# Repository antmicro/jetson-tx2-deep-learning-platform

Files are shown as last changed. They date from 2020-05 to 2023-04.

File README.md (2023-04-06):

# Antmicro TX2 Deep Learning Platform

Copyright (c) 2016-2023 [Antmicro](https://www.antmicro.com)



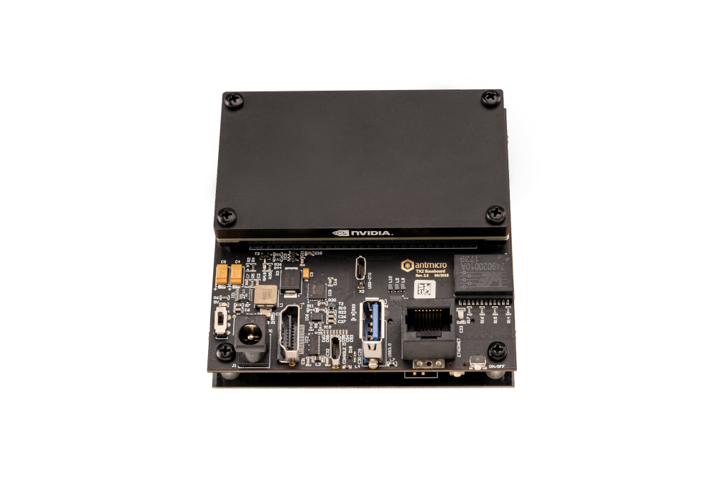
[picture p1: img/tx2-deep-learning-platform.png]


## Overview

This project contains open hardware design files for Antmicro's TX2 Deep Learning Platform built around NVIDIA [Jetson TX2 Module](https://developer.nvidia.com/embedded/jetson-tx2).
The TX2 Deep Learning Platform is a small, modular multi-camera kit for the NVIDIA Jetson TX2 module.
It consists of a baseboard and a camera adapter for interchangeable video input modules.
The baseboard is electrically compatible with the NVIDIA Jetson TX2/TXi and legacy TX1 module.
The baseboard offers typical IO interfaces along with miniPCIe/SATA expansion slots.
Thanks to its straightforward design, the camera adapter can be easily adjusted to custom image sensor setups composed of up to 6 independent cameras connected to the TX2 module over the MIPI CSI-2 interface.

## Project structure:

* `Baseboard` - contains PCB design files for the Jetson TX1/TX2/TX2i baseboard along with basic documentation
* `CameraAdapter` - contains PCB design files for the camera adapter, which break-routes the MIPI CSI-2 interfaces from the baseboard on three FFC connectors
* `img` - contains graphics for this README
* `3DModels` - contains files defining the mechanical model of the assembled platform

The PCB projects include basic documentation including schematics, assembly drawings (in the PDF format) along with the bill of material (BOM).
The PCB project files were prepared in Altium Designer 14.1

## Key Features

* USB 3.0 host interface
* HDMI output
* Micro USB OTG connector
* Serial debug console over micro USB
* Configurable mPCIe/mSATA card holder
* Gigabit Ethernet RJ45 connector
* 3x 50-pin FFC camera connectors exposing up to 6 MIPI CSI-2 camera interfaces
* Autostart circuitry
* RTC battery backup
* EEPROM for storing board ID/SN
* CAN interface (optional, not populated by default)
* 12-19V DC supply voltage
* 90 x 90 mm dimensions

## Getting started

The platform can be produced and assembled using the provided design files.
Please, refer to the mechanical layers for more information regarding the PCB stackup recommended for fabrication.
The platform accepts power supply voltage in the 12-19VDC range.
It is recommended to use a 12V 2A DC supply to power the platform.
The baseboard has a slide switch which activates the autostart function.
If the switch is on, the TX2 module will boot automatically. Otherwise, it will start after pressing the power button.
There is a [basic BSP](https://github.com/antmicro/tx2-deep-learning-kit-bsp) released by Antmicro for this hardware platform along with compilation and usage instructions.
The BSP configuration will most likely need to be adjusted for the video accessories used with the TX2 Deep Learning Platform.
Nevertheless, the remaining on-board IO interfaces should be working properly.

## Supported accessories

The TX2 Deep Learning Platform is compatible with a range of video accessories designed by Antmicro.

The board exposes MIPI CSI-2 interfaces using unified 50-pin connectors that are electrically compatible with a variety of video accessories created by Antmicro:

* [SDI-MIPI Video converter](https://github.com/antmicro/sdi-mipi-video-converter)
* [FRAMOS camera adapter](https://github.com/antmicro/framos-csi-adapter)
* [Allied Vision Alvium Camera Adapter](https://github.com/antmicro/alvium-flexible-csi-adapter)
* [HDMI-MIPI bridge](https://github.com/antmicro/hdmi-mipi-bridge)
* [OV9281 Dual camera board](https://github.com/antmicro/ov9281-camera-board)

## License

This project is licensed under the [Apache-2.0](LICENSE) license.

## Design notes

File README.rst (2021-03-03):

===================================
Antmicro TX2 Deep Learning Platform
===================================

Copyright (c) 2016-2021 `Antmicro <https://www.antmicro.com>`_

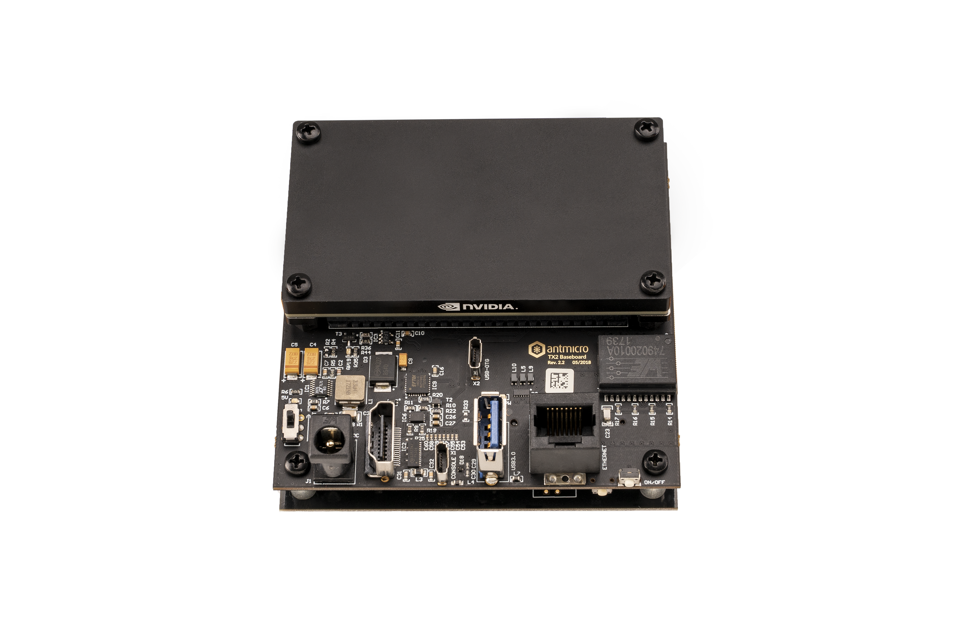
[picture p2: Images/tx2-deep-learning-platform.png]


Overview
========

This repository contains open hardware design files for Antmicro's TX2 Deep Learning Platform built around NVIDIA `Jetson TX2 Module <https://developer.nvidia.com/embedded/jetson-tx2>`_.
The TX2 Deep Learning Platform is a small, modular multi-camera kit for the NVIDIA Jetson TX2 module.
It consists of a baseboard and a camera adapter for interchangeable video input modules.
The baseboard is electrically compatible with the NVIDIA Jetson TX2/TXi and legacy TX1 module.
The baseboard offers typical IO interfaces along with miniPCIe/SATA expansion slots.
Thanks to its straightforward design, the camera adapter can be easily adjusted to custom image sensor setups composed of up to 6 independent cameras connected to the TX2 module over the MIPI CSI-2 interface.

Repository structure:
---------------------

* ``Baseboard`` - contains PCB design files for the Jetson TX1/TX2/TX2i baseboard along with basic documentation
* ``CameraAdapter`` - contains PCB design files for the camera adapter, which break-routes the MIPI CSI-2 interfaces from the baseboard on three FFC connectors
* ``Images`` - contains graphics for this README
* ``3DModels`` - contains files defining the mechanical model of the assembled platform

The PCB projects include basic documentation including schematics, assembly drawings (in the PDF format) along with the bill of material (BOM).
The PCB project files were prepared in Altium Designer 14.1

Key Features
============

* USB 3.0 host interface
* HDMI output
* Micro USB OTG connector
* Serial debug console over micro USB
* Configurable mPCIe/mSATA card holder
* Gigabit Ethernet RJ45 connector
* 3x 50-pin FFC camera connectors exposing up to 6 MIPI CSI-2 camera interfaces
* Autostart circuitry
* RTC battery backup
* EEPROM for storing board ID/SN
* CAN interface (optional, not populated by default)
* 12-19V DC supply voltage
* 90 x 90 mm dimensions

Board layout & dimensions
=========================

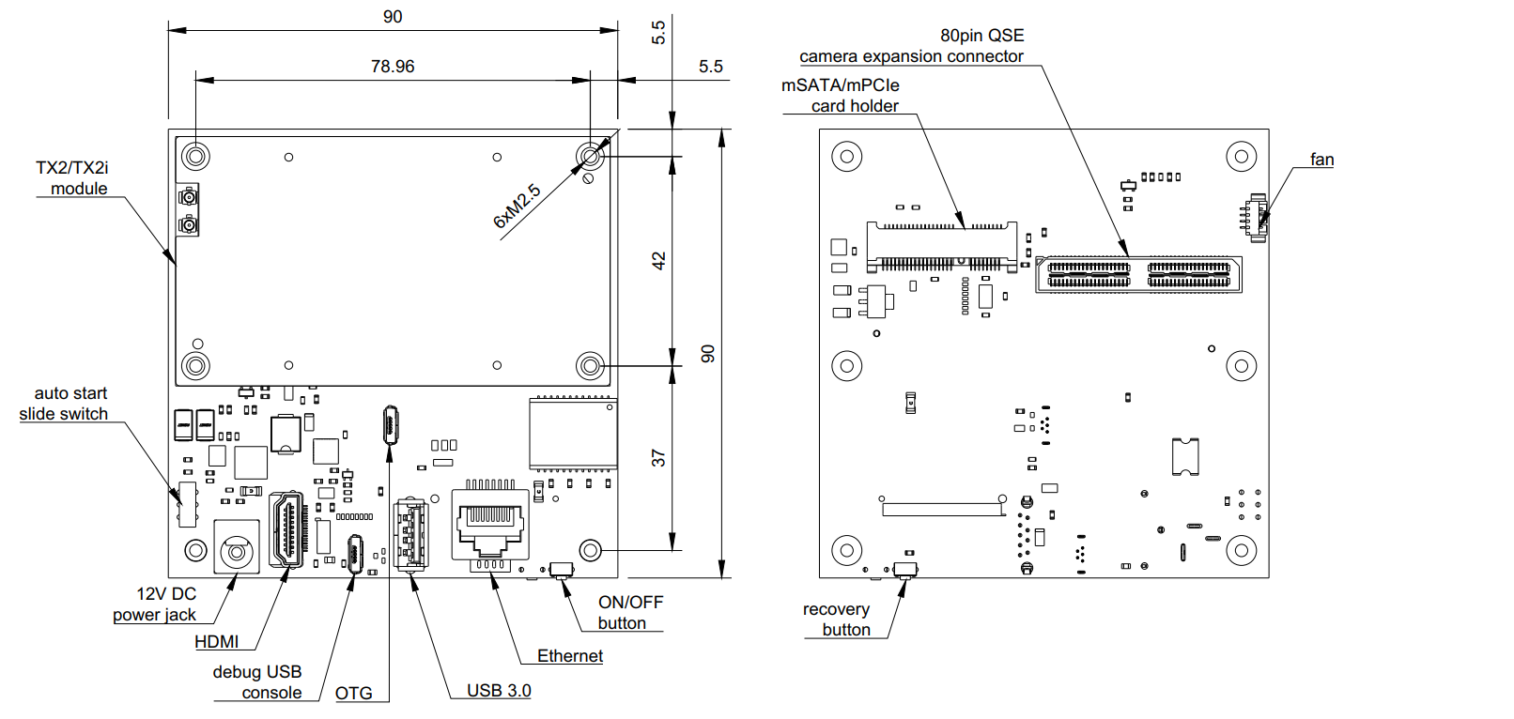
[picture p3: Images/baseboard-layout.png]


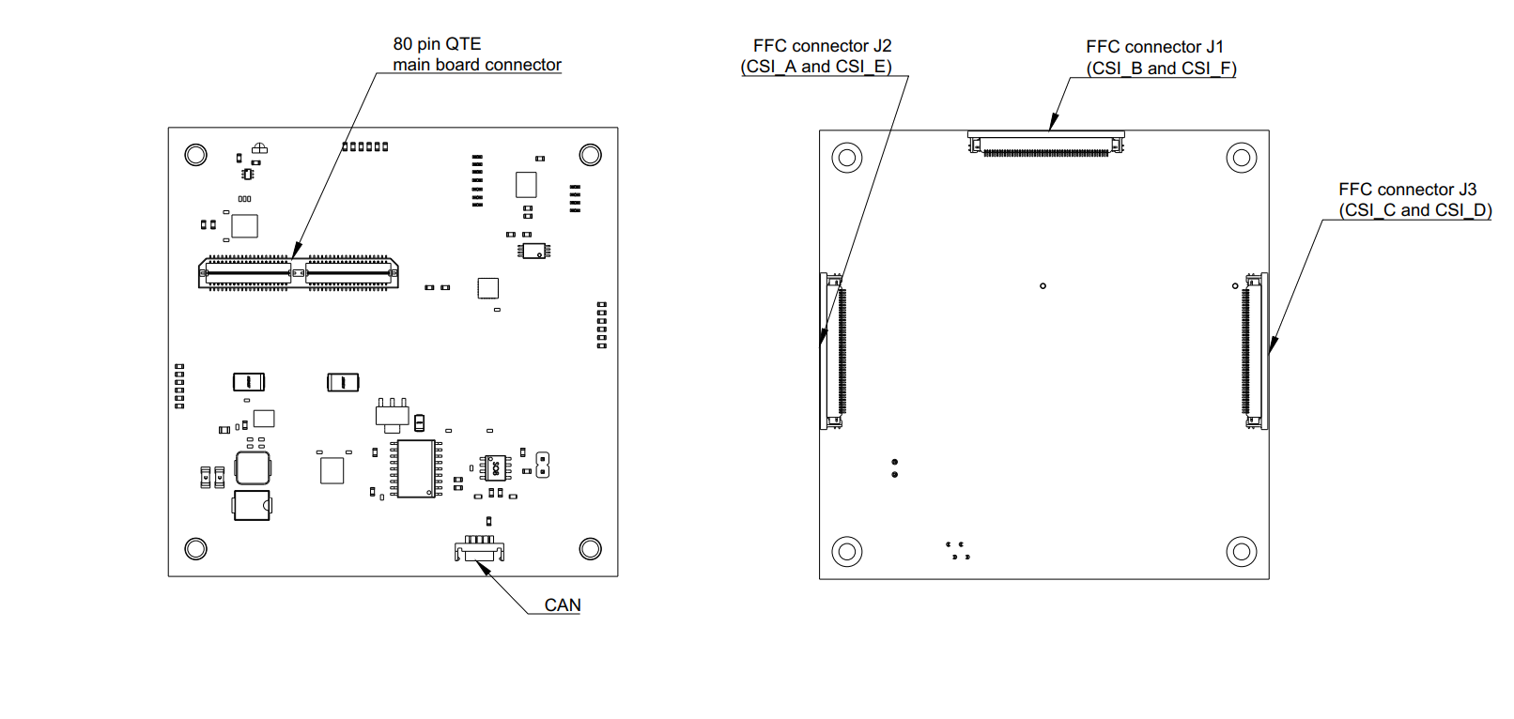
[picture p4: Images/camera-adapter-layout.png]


Getting started
===============

The platform can be produced and assembled using the provided design files.
Please, refer to the mechanical layers for more information regarding the PCB stackup recommended for fabrication.
The platform accepts power supply voltage in the 12-19VDC range.
It is recommended to use a 12V 2A DC supply to power the platform.
The baseboard has a slide switch which activates the autostart function.
If the switch is on, the TX2 module will boot automatically. Otherwise, it will start after pressing the power button.
There is a `basic BSP <https://github.com/antmicro/tx2-deep-learning-kit-bsp>`_ released by Antmicro for this hardware platform along with compilation and usage instructions.
The BSP configuration will most likely need to be adjusted for the video accessories used with the TX2 Deep Learning Platform.
Nevertheless, the remaining on-board IO interfaces should be working properly.

Supported accessories
=====================

The TX2 Deep Learning Platform is compatible with a range of video accessories designed by Antmicro.
Some of them, like the `OV9281 Camera Board <https://github.com/antmicro/ov9281-camera-board>`_ are available as Open Hardware designs.

License
=======

`Apache-2.0 <LICENSE>`_

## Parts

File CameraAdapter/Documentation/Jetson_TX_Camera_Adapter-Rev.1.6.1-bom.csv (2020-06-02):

Designator | Value | Description | Manufacturer | Part Symbol | Quantity
C1 | 22u | Tantalum SMT Capacitor 22uF Case KEMET_C | KEMET | T491C226K025AT | 1
C2 | 470n/16V | MLCC SMT Capacitor 470nF 0402 16V | TDK | C1005X5R1C474K050BC | 1
C3, C4 | 47u | MLCC SMT Capacitor 47uF 1206 | MURATA | GRM31CC80J476KE18L | 2
C5 | 10p | MLCC SMT Capacitor 10pF 0402 | MULTICOMP | MC0402N100D500CT | 1
C6 | 10n | MLCC SMT Capacitor 10nF 0402 | AVX | 04025G103ZAT2A | 1
C7 | 470p | MLCC SMT Capacitor 470pF 0402 | MULTICOMP | MC0402B471J500CT | 1
C15 | 10u | Tantalum SMT Capacitor 10uF Case KEMET_C | KEMET | T491C106K025AT | 1
C16 | 10u | Tantalum SMT Capacitor 10uF Case KEMET_A | VISHAY | 293D106X9016A2TE3 | 1
C18, C19, C20 | 100n | MLCC SMT Capacitor 100nF 0402 | MULTICOMP | MC0402X104M100CT | 3
C28, C61 | 100n | MLCC SMT Capacitor 100nF 0603 | WALSIN | 0603B104K500CT | 2
D1 | MBRS540T3G | ON SEMICONDUCTOR MBRS540T3G Rectifier Diode, Single, 40 V, 5 A, 500 mV, 190 A | ON SEMICONDUCTOR | MBRS540T3G | 1
IC1 | TCA9548ARGER | TCA9548ARGER I2C SWITCH W/ RESET, 8-CH, VQFN-24 | TEXAS INSTRUMENTS | TCA9548ARGER | 1
IC4 | LT3976EMSE#PBF | LINEAR TECHNOLOGY LT3976EMSE#PBF DC-DC CONVERTER, 2MHZ, 5A, MSOP-16 | LINEAR TECHNOLOGY | LT3976EMSE#PBF | 1
IC6 | NCV1117ST50T3G | ON SEMICONDUCTOR NCV1117ST50T3G Fixed LDO Voltage Regulator, 20V in, 1.07V Dropout, 5V/1A out, SOT-223-3 | ON SEMICONDUCTOR | NCV1117ST50T3G | 1
IC7 | NTS0104PW | 4 bit voltage level translator | NXP | NTS0104PW | 1
IC14 | TCA9554A | Remote 8bit I2C SMBus I/O expander | Texas Instruments | TCA9554A | 1
IC15 | RM24C128DS-LTAI-B | EEPROM with UID and OTP registers. | Adesto | RM24C128DS-LTAI-B | 1
J1, J2, J3 | 68715014522 | 0.50mm SMT ZIF Horizontal Bottom Contact WR-FPC | WURTH ELEKTRONIK | 68715014522 | 3
J6 | QTE-040-03-L-D-A | SAMTEC QTE-040-03-L-D-A Stacking Board Connector, Dual Row, QTE Series, 80 Contacts, Header, 0.8 mm, Surface Mount | SAMTEC | QTE-040-03-L-D-A | 1
L1 | 74437346033 | 3.3 uH, 5.0A, 0.03 ohm, SMD Power Inductor | WURTH ELEKTRONIK | 74437346033 | 1
LED1 | LED-LiteON-LTST-S326KGJRKT | Standard LEDs - SMD Green/Red Clear 571nm/631nm | Lite-On | LTST-S326KGJRKT | 1
Q1 | Si1922EDH | 20 V, dual N-channel Trench MOSFET | Vishay | Si1922EDH | 1
R2, R7 | 470R | SMT Resistor 470R 0603 | BOURNS | CR0603-JW-471GLF | 2
R3 | 1M | SMT Resistor 1M 0603 0.1% | TE | CPF0603B1M0E | 1
R4 | 130k | SMT Resistor 2R 0402 | MULTICOMP | MCMR04X1303FTL | 1
R5 | 2R | SMT Resistor 2R 0402 | MULTICOMP | MC00625W040212R0 | 1
R6 | 576k | SMT Resistor 576k 0805 0.1% | PANASONIC ELECTRONIC COMPONENTS | ERA-6AEB5763V | 1
R16, R17, R18, R19, R24, R25, R27, R31, R32, R39, R40, R54, R76, R77 | 2k | SMT Resistor 2k 0603 | MULTICOMP | MCMR06X2001FTL | 14
R42, R43, R47 | 2k2 | SMT Resistor 2k2 0603 | MULTICOMP | MCMR06X2201FTL | 3
R49, R51, R53, R56, R58, R60, R62, R64, R66, R69, R70 | 0R | SMT Resistor 0402 | MULTICOMP | MCMR04X000 PTL | 11
R72, R73, R74, R75 | 0R | SMT Resistor 0R 0603 | BOURNS | CR0603-J/-000ELF | 4
SP1, SP2, SP3, SP4 | 9774030960R | ROUND SPACER STEEL 3MM unthreaded | WURTH ELEKTRONIK | 9774030960 | 4

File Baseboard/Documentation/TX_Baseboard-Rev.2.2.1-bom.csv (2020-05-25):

Designator | Value | Description | Manufacturer | Quantity | Layer | Part Symbol
5V, GP19, PCI/SATA | KPT-1608SGC | LED Green 0603 case | KINGBRIGHT | 3 | Top, Top, Bottom | KPT-1608SGC
AUTO START | JS202011CQN | Sub-Miniature Slide Switch | C&K | 1 | Top | JS202011CQN
C1, C44, C45 | 10p | MLCC SMT Capacitor 10pF 0603 | JOHANSON TECHNOLOGY | 3 | Top, Bottom, Bottom | 251R14S100GV4T
C2 | 470n | MLCC SMT Capacitor 470nF 0603 | TDK | 1 | Top | C1608X5R1H474K080AB
C3 | 47u | MLCC SMT Capacitor 47uF 1206 | MURATA | 1 | Top | GRM31CC80J476KE18L
C4, C5 | 22u | Tantalum SMT Capacitor 22uF Case KEMET_C | KEMET | 2 | Top | T491C226K025AT
C6, C11, C32, C46, C47, C48 | 10n | MLCC SMT Capacitor 10nF 0603 | AVX | 6 | Top, Top, Top, Bottom, Bottom, Bottom | 06031C103JAT2A
C7 | 470p | MLCC SMT Capacitor 470pF 0603 | AVX | 1 | Top | 06031C471JAT2A
C8, C17, C35 | 10u | Tantalum SMT Capacitor 10uF Case KEMET_A | VISHAY | 3 | Bottom, Bottom, Top | 293D106X9016A2TE3
C9 | 4u7 | Tantalum SMT Capacitor 4u7F Case KEMET_A | KEMET | 1 | Top | T491A475K010AT
C10, C16, C26, C27, C28, C31, C40, C41, C43, C61 | 100n | MLCC SMT Capacitor 100nF 0603 | WALSIN | 10 | Top, Top, Top, Top, Top, Top, Top, Top, Top, Bottom | 0603B104K500CT
C12 | 4u7 | MLCC SMT Capacitor 4u7F 0603 | MULTICOMP | 1 | Top | MC0603X475K6R3CT
C13, C14, C36, C37, C38, C39, C52 | 10u | MLCC SMT Capacitor 10uF 0603 | MULTICOMP | 7 | Bottom, Bottom, Bottom, Top, Bottom, Bottom, Top | MC0603X106M6R3CT
C15 | 10n | MLCC SMT Capacitor 10nF 1206 | MULTICOMP | 1 | Bottom | MC1206B103K631CT
C18 | 10u | Tantalum SMT Capacitor 10uF Case KEMET_C | KEMET | 1 | Top | T491C106K025AT
C19, C20, C21, C22, C24, C25, C49, C50, C53, C54, C55, C56, C57, C58, C59, C60 | 100n | MLCC SMT Capacitor 100nF 0402 | MULTICOMP | 16 | Bottom, Bottom, Bottom, Bottom, Bottom, Bottom, Bottom, Bottom, Top, Top, Top, Top, Top, Top, Top, Top | MC0402X104M100CT
C23 | 1n | MLCC SMT Capacitor 1nF 1206 | AVX | 1 | Top | 12061A102JAT2A
C29, C30 | 47p | MLCC SMT Capacitor 47pF 0402 | KEMET | 2 | Top | C0402C470J5GACTU
C33 | 100u | Tantalum SMT Capacitor 100uF Case KEMET_A | VISHAY | 1 | Bottom | 298D107X06R3A2T
C34, C42 | 1u | MLCC SMT Capacitor 1uF 0603 | MULTICOMP | 2 | Bottom, Top | MC0603X105M6R3CT
C51 | 80mF | CAP 80MF 3.3V SURFACE MOUNT | SEIKO | 1 | Top | XH414HG-IV01E
D1, D2, D18 | TPD2E009DRTR | ESD Suppressors 2-CH | Texas Instruments | 3 | Bottom, Bottom, Top | TPD2E009DRTR
D3 | MBRS540T3G | ON SEMICONDUCTOR MBRS540T3G Rectifier Diode, Single, 40 V, 5 A, 500 mV, 190 A | ON SEMICONDUCTOR | 1 | Top | MBRS540T3G
D4 | SMBJ20CA-TR | DIODE, TVS, 20V, 600W | STMICROELECTRONICS | 1 | Bottom | SMBJ20CA-TR
D7 | 1N4148WS | Diode small signal | MULTICOMP | 1 | Top | 1N4148WS
D8 | TPD6E05U06 | ESD Suppressors 6-CH Pass through layout | Texas Instruments | 1 | Top | TPD6E05U06RVZR
F1 | 3.0A | 3.0A, 6V, PTC Resettabe Fuse | BOURNS | 1 | Bottom | MF-LSMF300X-2
HDMI | Molex-04765-1000 | HDMI connector vertical | Molex | 1 | Top | 47659-1000
IC1 | LT3976EMSE#PBF | LINEAR TECHNOLOGY LT3976EMSE#PBF DC-DC CONVERTER, 2MHZ, 5A, MSOP-16 | LINEAR TECHNOLOGY | 1 | Top | LT3976EMSE#PBF
IC2 | TPD8S009 | 8-Channel ESD Protection for DisplayPort and HDMI | TEXAS INSTRUMENTS | 1 | Top | TPD8S009DSMR
IC3 | LP2992AIM5-1.8 | LDO 1.8V 250mA | TEXAS INSTRUMENTS | 1 | Top | LP2992AIM5-1.8/NOPB
IC4 | LM3671MF-1.5 | DC/DC Buck Converter | TEXAS INSTRUMENTS | 1 | Bottom | LM3671MF-1.5/NOPB
IC5, IC7 | AP1117E33G-13 | IC, LDO, REG, 3.3V, SOT223 | DIODES INC. | 2 | Bottom, Top | AP1117E33G-13
IC6 | PCA9517ATP | I2C BUS REPEATER W/ LEVEL TRANS, HWSON-8 | NXP | 1 | Top | PCA9517ATP
IC8 | SEAM-50-02.0-S-08-2-A-K-TR | TX1 module (board connector) | Samtec | 1 | Top | SEAM-50-02.0-S-08-2-A-K-TR
IC9 | FT232RQ | USB to serial UART interface | FTDI | 1 | Top | FT232RQ-REEL
IC10 | NCP380HSNAJAAT1G | POWER LOAD SWITCH, HIGH SIDE | ON Semiconductor | 1 | Bottom | NCP380HSNAJAAT1G
IC11 | LM3881 | TEXAS INSTRUMENTS LM3881MME/NOPB Power Sequencer, 3-Monitors, 2.7V-5.5Vin,VSSOP-8 | TEXAS INSTRUMENTS | 1 | Top | LM3881MME
IC12 | SN74LVC1G86DCKR | 2 input XOR gate | Texas Instruments | 1 | Top | SN74LVC1G86DCKR
IC13 | CBTL02042ABQ | IC MUX/DEMUX 2:1 PCI 20DHVQFN | NXP Semiconductors | 1 | Bottom | CBTL02042ABQ,115
IC14 | TCA9554ADBQR | Remote 8bit I2C SMBus I/O expander | Texas Instruments | 1 | Top | TCA9554ADBQR
IC15 | RM24C128DS-LTAI-B | EEPROM with UID and OTP registers. | Adesto | 1 | Top | RM24C128DS-LTAI-B
J1 | WE_694106402002 | WURTH ELEKTRONIK 694106402002 POWER ENTRY, JACK, 2MM, VERTICAL THT, 3A | WURTH ELEKTRONIK | 1 | Top | 694106402002
J2 | QSE-040-01-L-D-A | SAMTEC QSE-040-01-L-D-A Stacking Board Connector, Dual Row, QSE Series, Receptacle, 0.8 mm, 80 Contacts, Surface Mount | SAMTEC | 1 | Bottom | QSE-040-01-L-D-A
J3 | WE_634108149621 | Modular Connectors / Ethernet Connectors WR-MJ Mod Jk 8P8C Solder Tab w/Mylar | WURTH ELEKTRONIK | 1 | Top | 634108149621
J4 | WE_692121430000 | WURTH ELEKTRONIK 692121430000 USB Connector, USB Type A, USB 3.0, Receptacle, 9 Ways, PCB Mount, Vertical | WURTH ELEKTRONIK | 1 | Top | 692121430000
J5 | Molex_67910-5700 | PCIe Mini Card Holder 4mm | Molex | 1 | Bottom | 67910-5700
J6 | 653104131822 | HEADER 4POS MALE HORIZ 1.25MM SMD | WURTH ELEKTRONIK | 1 | Bottom | 653104131822
L1 | IHLP2525CZER3R3M01 | 3.3 uH, +/- 20%, Shielded, 0.02 ohm, 8 A | VISHAY | 1 | Top | IHLP2525CZER3R3M01
L3 | 742792022 | WURTH ELEKTRONIK - 742792022 - FERRITE BEAD, 0.05OHM, 2A, 0805 | WURTH ELEKTRONIK | 1 | Top | 742792022
L4 | BLM18SG121TN1D | FERRITE BEAD, 0.025OHM, 3A, 0603 | MURATA | 1 | Top | BLM18SG121TN1D
L5, L9, L10, L11, L13 | DLW21SN900SQ2 | Common mode choke | MURATA | 5 | Top, Top, Top, Bottom, Bottom | DLW21SN900SQ2L
L6 | BLM18EG221SN1D | MURATA BLM18EG221SN1D FERRITE BEAD, 0.05OHM, 2A, 0603 | MURATA | 1 | Bottom | BLM18EG221SN1D
L7, L12 | BLM18PG330SN1D | MURATA BLM18PG330SN1D FERRITE BEAD, 0.025OHM, 3A, 0603 | MURATA | 2 | Top, Bottom | BLM18PG330SN1D
L8 | LQH3NPN2R2NM0L | INDUCTOR, 2.2 uH, +/- 30%, 1212, 90 MHz, 0.073 ohm | MURATA | 1 | Bottom | LQH3NPN2R2NM0L
LED2 | KPT-1608EC | LED Red 0603 case | KINGBRIGHT | 1 | Top | KPT-1608EC
M1, M2, M3, M4 | 9774110360 | M3x11.6 | WURTH ELEKTRONIK | 4 | Bottom | 9774110360
M6, M7 | 9774030360 | M3x3 | WURTH ELEKTRONIK | 2 | Bottom | 9774030360
M8, M9, M10, M11 |  |  | Dremec | 4 | None | 316/3.2x07
On/Off, REC | TL3340AF160QG | E-SWITCH TL3340AF160QG SWITCH, TACTILE SPST 50mA, SMD GULL WING | E-SWITCH | 2 | Top, Bottom | TL3340AF160QG
PCIE | MECH-Molex-48099-5701 | PCI Express/PCI Connectors LATCH ASSY FOR MINIP CI-ENEW TYPE W/COVER | Molex | 1 | None | 48099-5701
R1 | 1M | SMT Resistor 1M 0603 | BOURNS | 1 | Top | CR0603-JW-105GLF
R3, R20, R22 | 4k7 | SMT Resistor 4k7 0603 | BOURNS | 3 | Bottom, Top, Top | CR0603-FX-4701ELF
R4, R24, R28, R37, R44, R72 | 0R | SMT Resistor 0R 0603 | BOURNS | 6 | Top, Bottom, Bottom, Bottom, Top, Top | CR0603-J/-000ELF
R5 | 2R | SMT Resistor 2R 0603 | MULTICOMP | 1 | Top | MCSR06W2R00FTL
R6, R18 | 470R | SMT Resistor 470R 0603 | BOURNS | 2 | Top, Bottom | CR0603-JW-471GLF
R7 | 54k9 | SMT Resistor 54k9 0603 | PANASONIC ELECTRONIC COMPONENTS | 1 | Top | ERJ3EKF5492V
R8 | 316k | SMT Resistor 316k 0603 | MULTICOMP | 1 | Top | MC0063W06031316K
R9, R10, R11, R19, R21, R32, R34, R36, R38, R39, R45, R46 | 10k | SMT Resistor 10k 0603 | BOURNS | 12 | Top, Top, Top, Top, Bottom, Top, Bottom, Top, Top, Bottom, Top, Top | CR0603-JW-103ELF
R13 | 47k | SMT Resistor 47k 0603 | MULTICOMP | 1 | Top | MCWR06X4702FTL
R14, R15, R16, R17 | 75R | SMT Resistor 75R 0603 | MULTICOMP | 4 | Top | MCWR06X75R0FTL
R26, R42, R43 | 2k2 | SMT Resistor 2k2 0603 | MULTICOMP | 3 | Bottom, Bottom, Top | MCMR06X2201FTL
R27 | 13k | SMT Resistor 13k 0603 | PANASONIC ELECTRONIC COMPONENTS | 1 | Bottom | ERJ3GEYJ133V
R29, R40, R41 | 22R | SMT Resistor 22R 0603 | BOURNS | 3 | Top, Bottom, Bottom | CR0603-JW-220GLF
R30, R47, R48 | 100R | SMT Resistor 100R 0603 | MULTICOMP | 3 | Bottom, Top, Top | MC0063W06035100R
R31, R35 | 330R | SMT Resistor 330R 0603 | BOURNS | 2 | Bottom, Top | CR0603-FX-3300GLF
R51, R52, R53, R55, R56, R64, R65, R69, R70 | 2k2 | RES, 2k2, 0402, 5% | MULTICOMP | 9 | Top | MCWR04X2201FTL
R60, R66 | 0R | SMT Resistor 0402 | MULTICOMP | 2 | Top | MCMR04X000 PTL
T1 | 749020010A | LAN TRANSFORMER, 10/100/1000 BASE-T | WURTH ELEKTRONIK | 1 | Top | 749020010A
T2 | BSS138PW | MOSFET, N CH, 60V, 0.2A | NXP | 1 | Top | BSS138PW
T3, T4, T5 | PMV16XN | MOSFET Transistor, N Channel, 6.8 A, 20 V, 0.016 ohm, 4.5 V | NXP | 3 | Top, Top, Bottom | PMV16XN
T6, T7 | BSS138AKA | MOSFET, N CH, 60V, 0.2A | NXP | 2 | Top | BSS138AKA
X1, X2 | USB3106-30-0230-A | Micro USB A/B TH Vertical | GLOBAL CONNECTOR TECHNOLOGY | 2 | Top | USB3105-30-A

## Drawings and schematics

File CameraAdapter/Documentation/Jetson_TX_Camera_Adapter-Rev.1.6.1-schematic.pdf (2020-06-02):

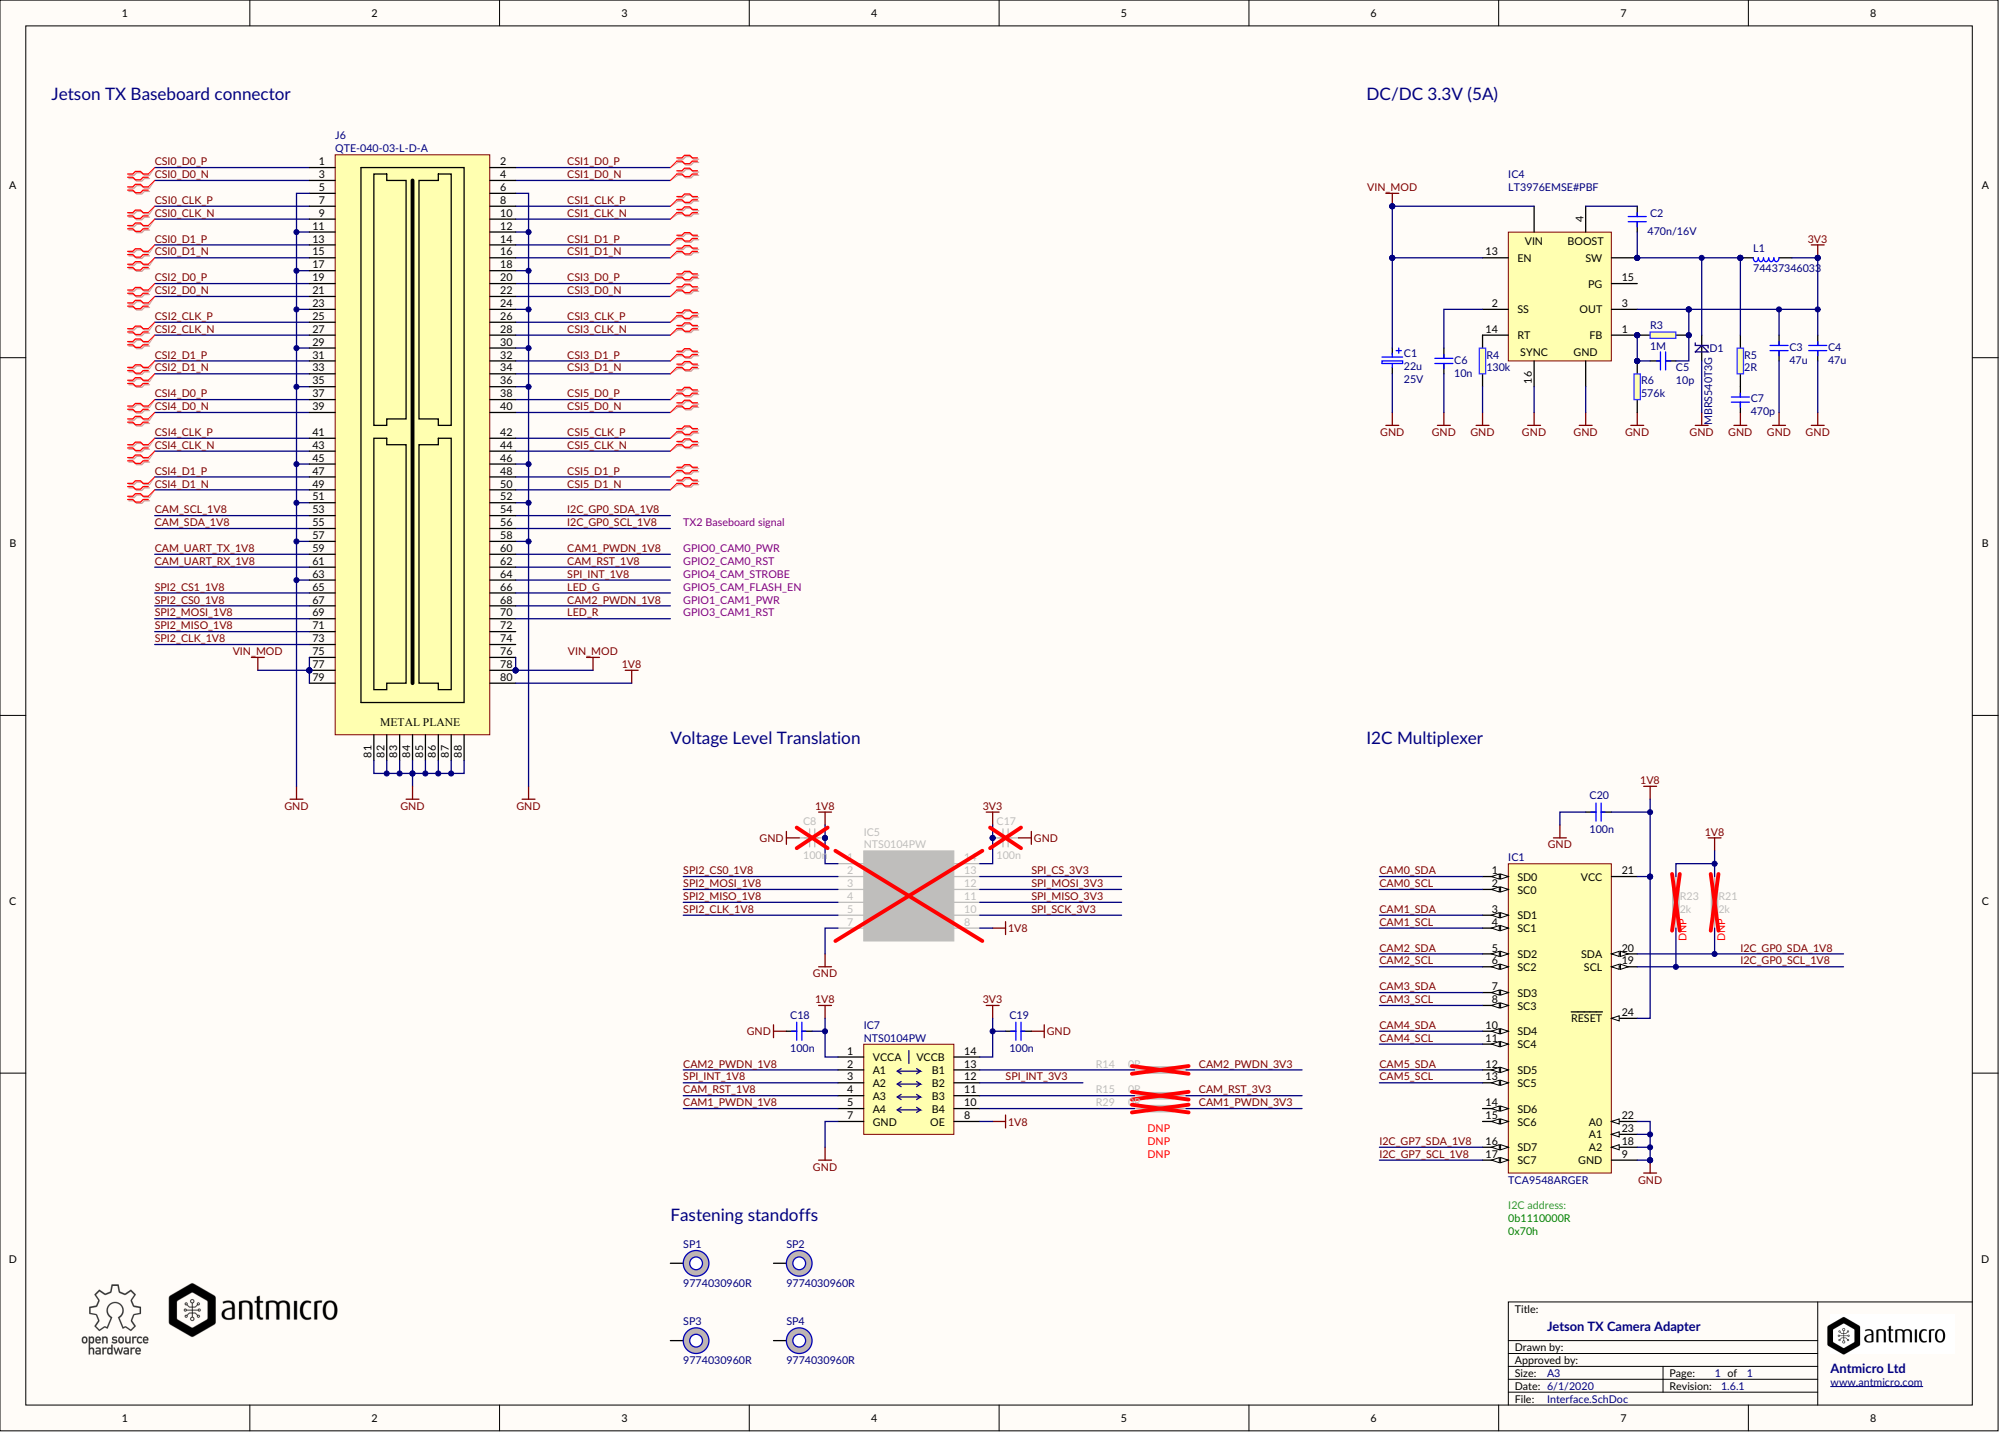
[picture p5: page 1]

Jetson TX Baseboard connector

Title:
Jetson TX Camera Adapter

Size: A3 | Page: 1 of 1
Date: 6/1/2020 | Revision: 1.6.1

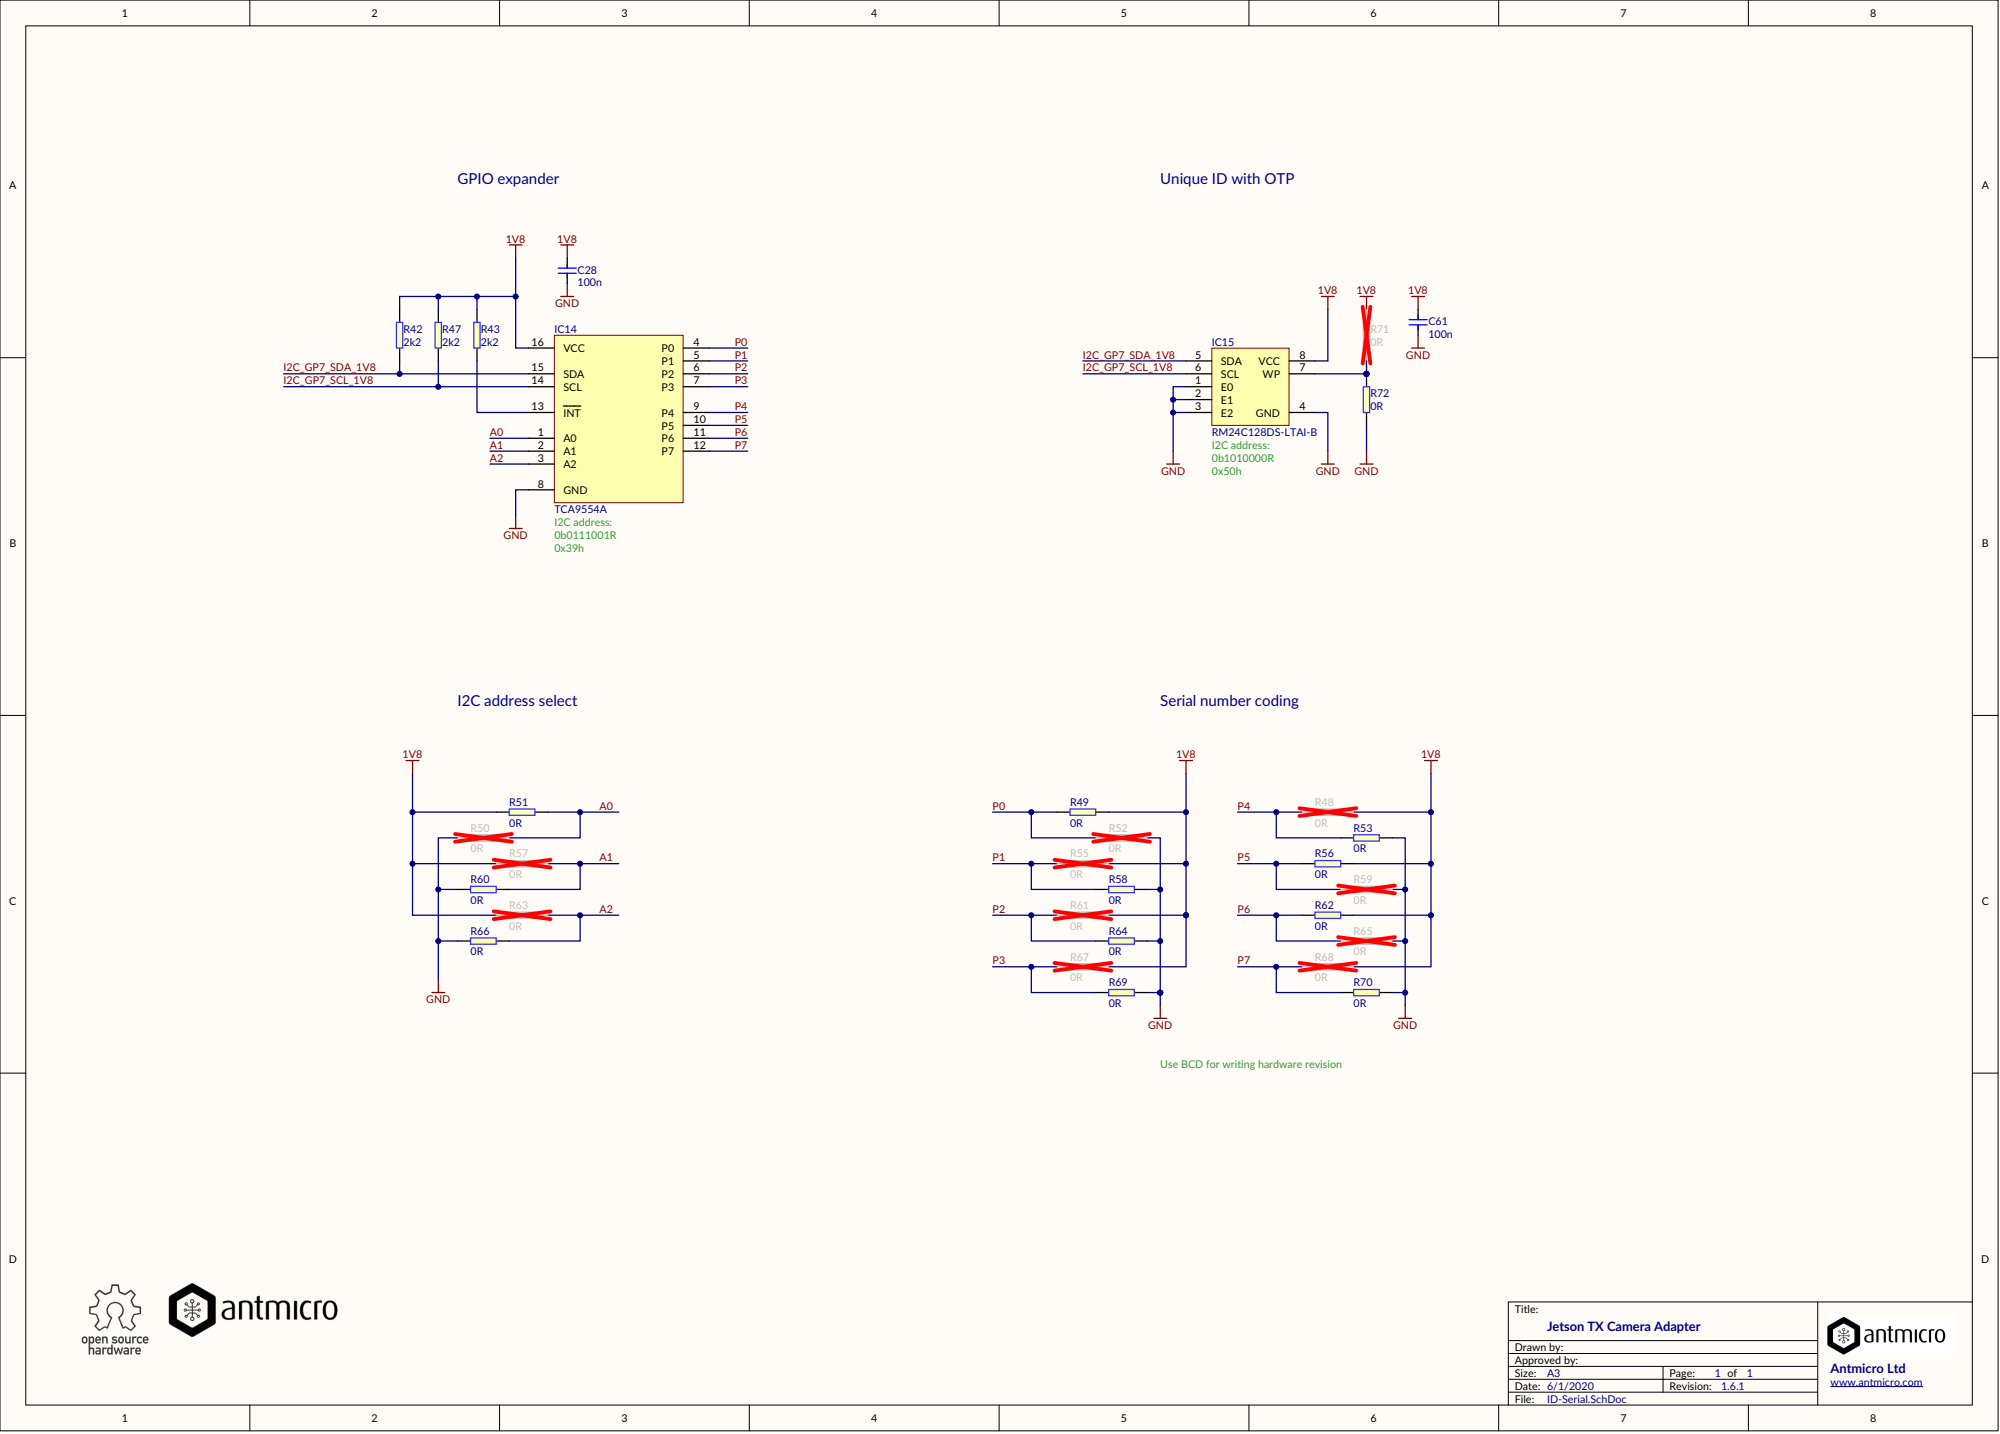
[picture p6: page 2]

Unique ID with OTP

Use BCD for writing hardware revision

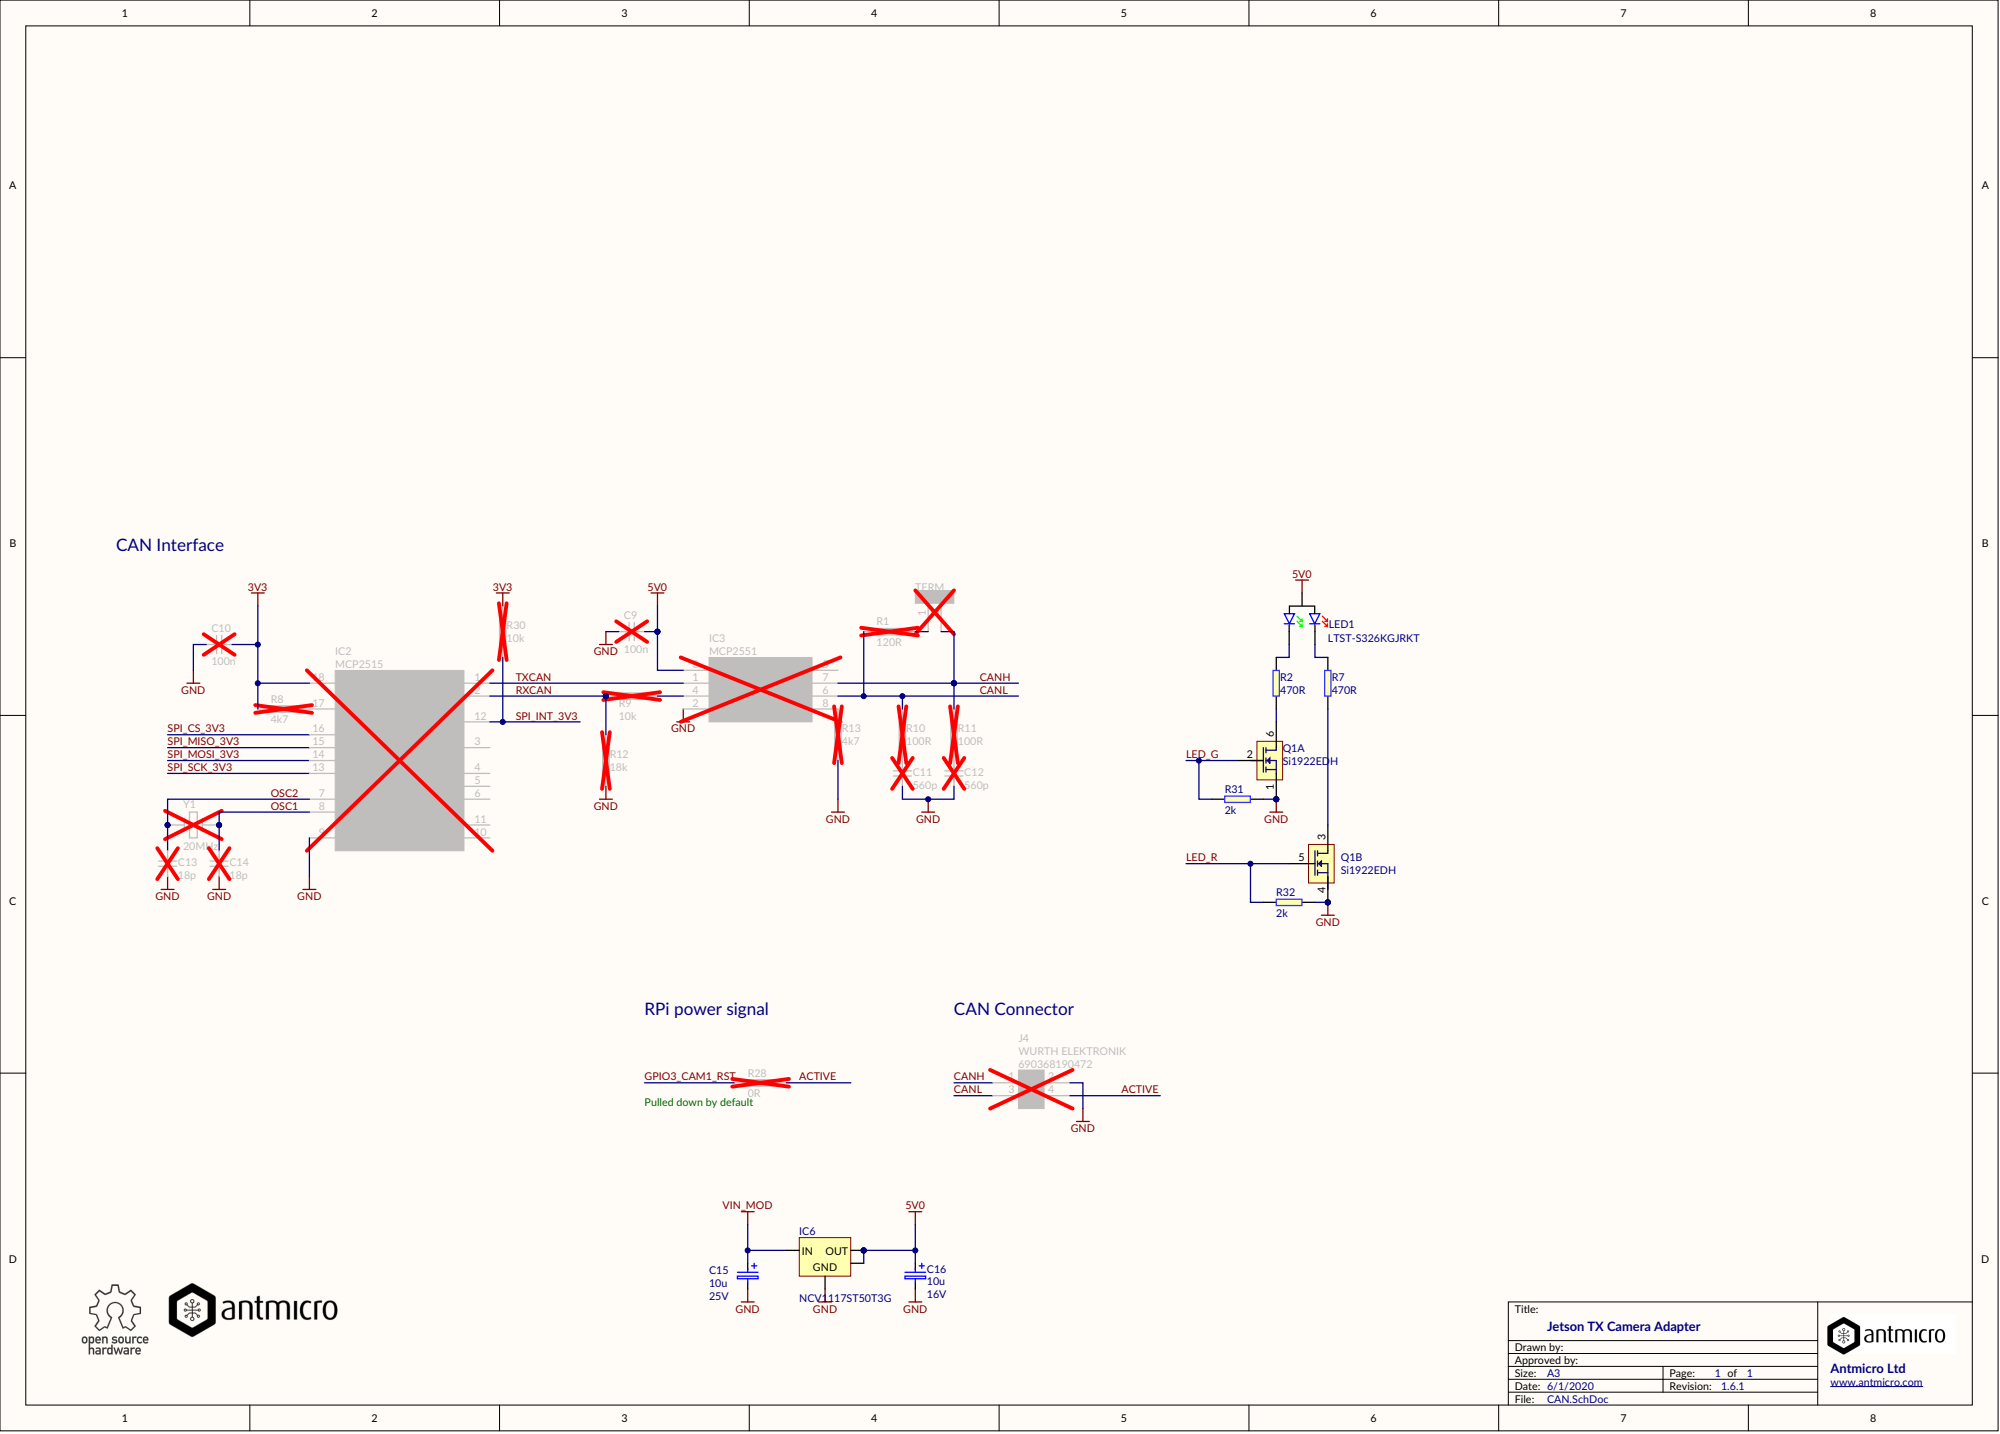
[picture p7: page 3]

Pulled down by default

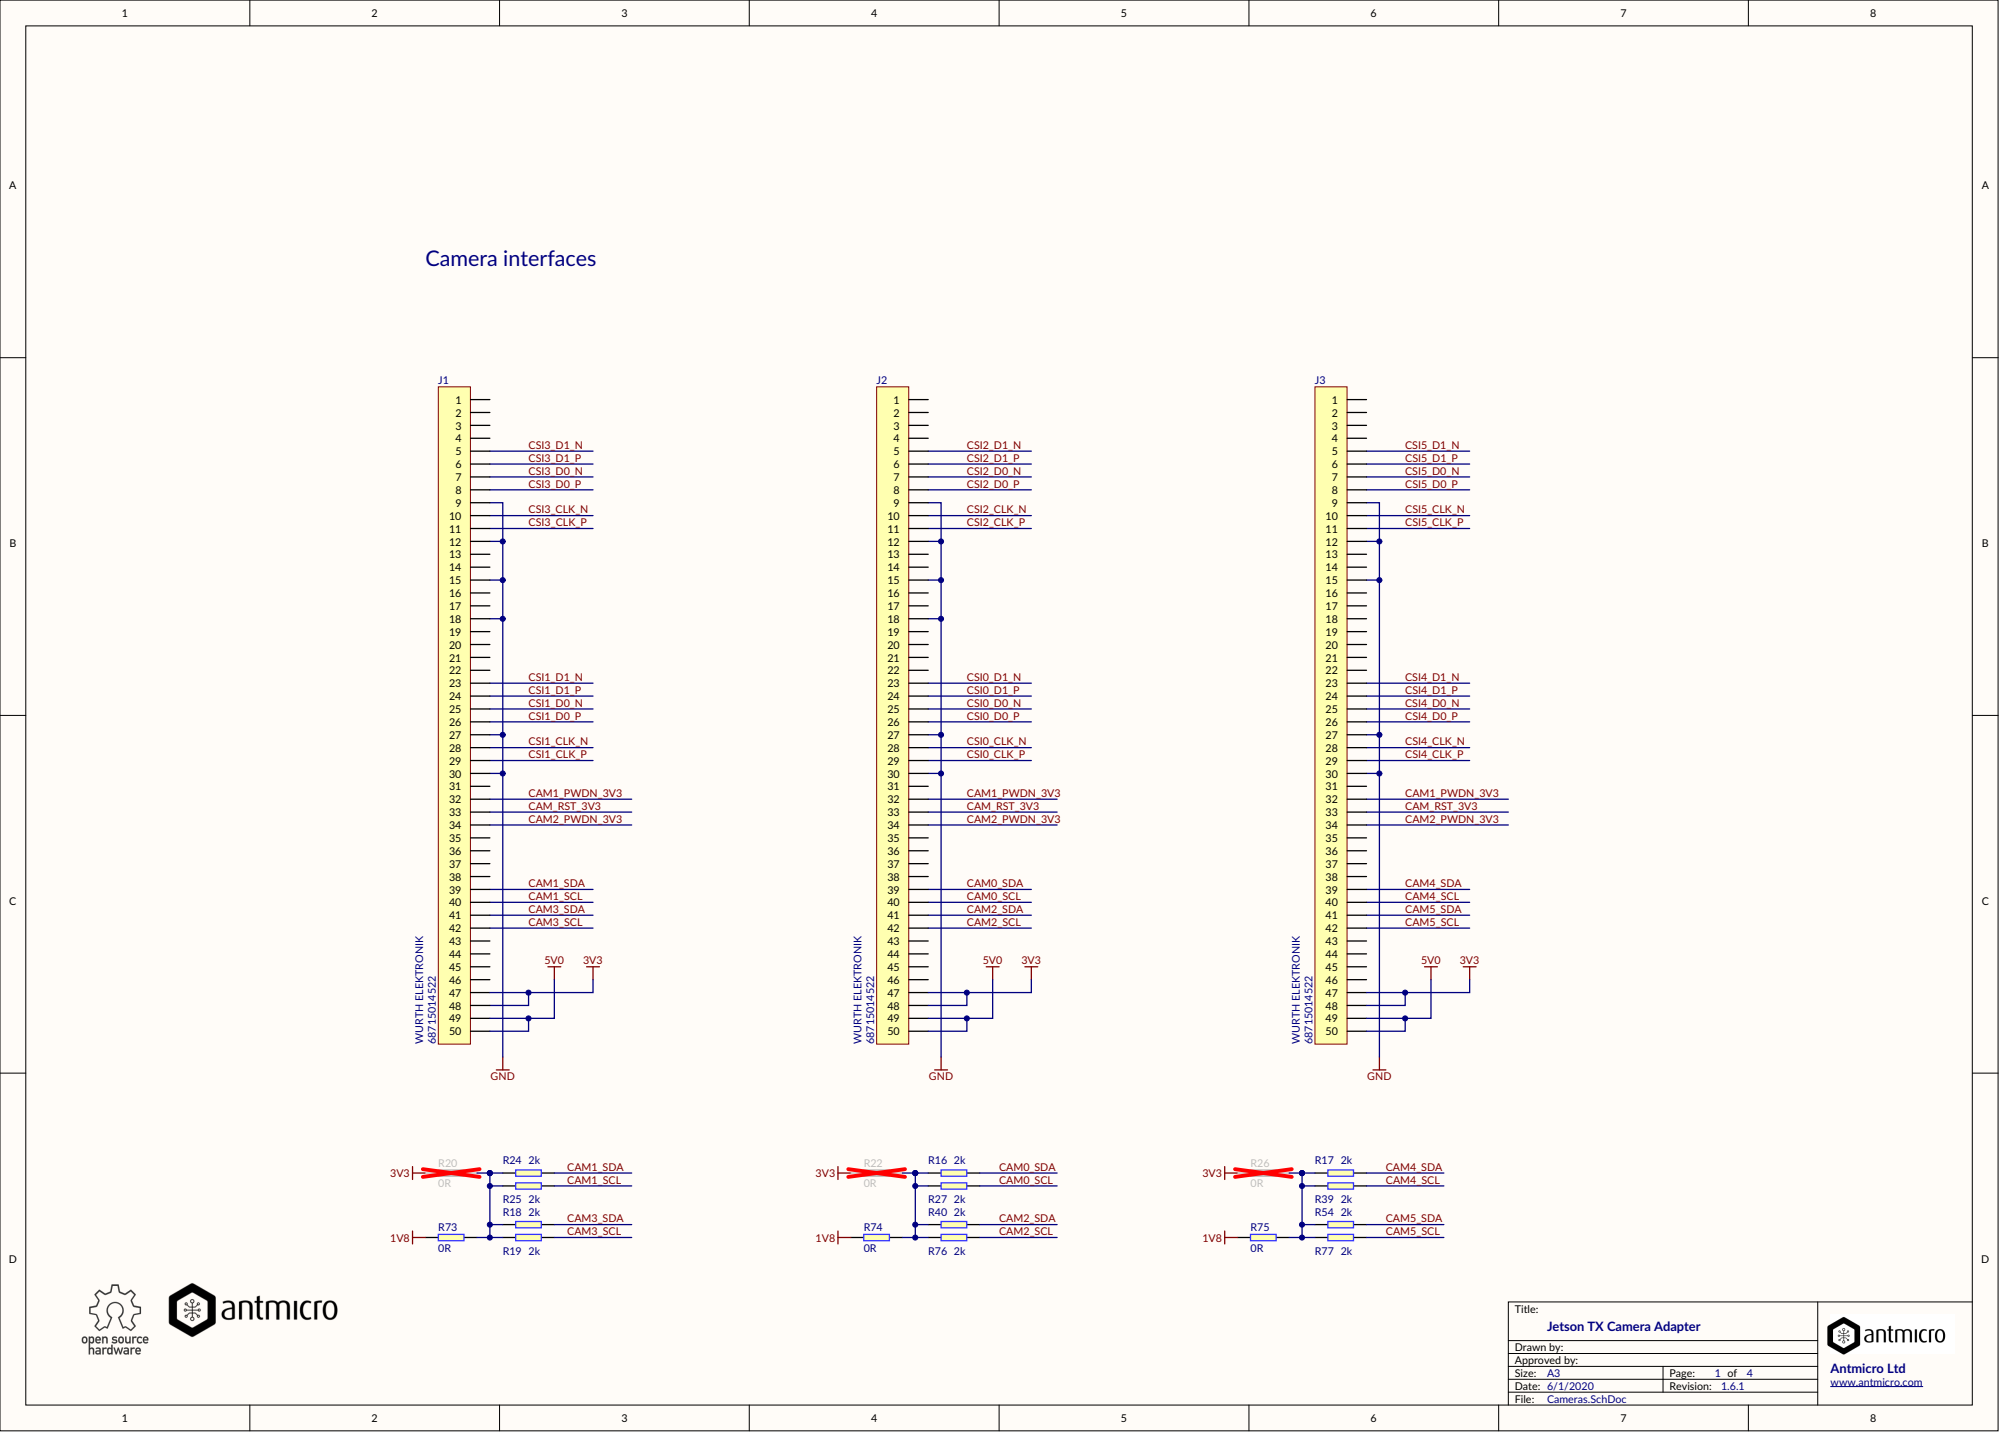
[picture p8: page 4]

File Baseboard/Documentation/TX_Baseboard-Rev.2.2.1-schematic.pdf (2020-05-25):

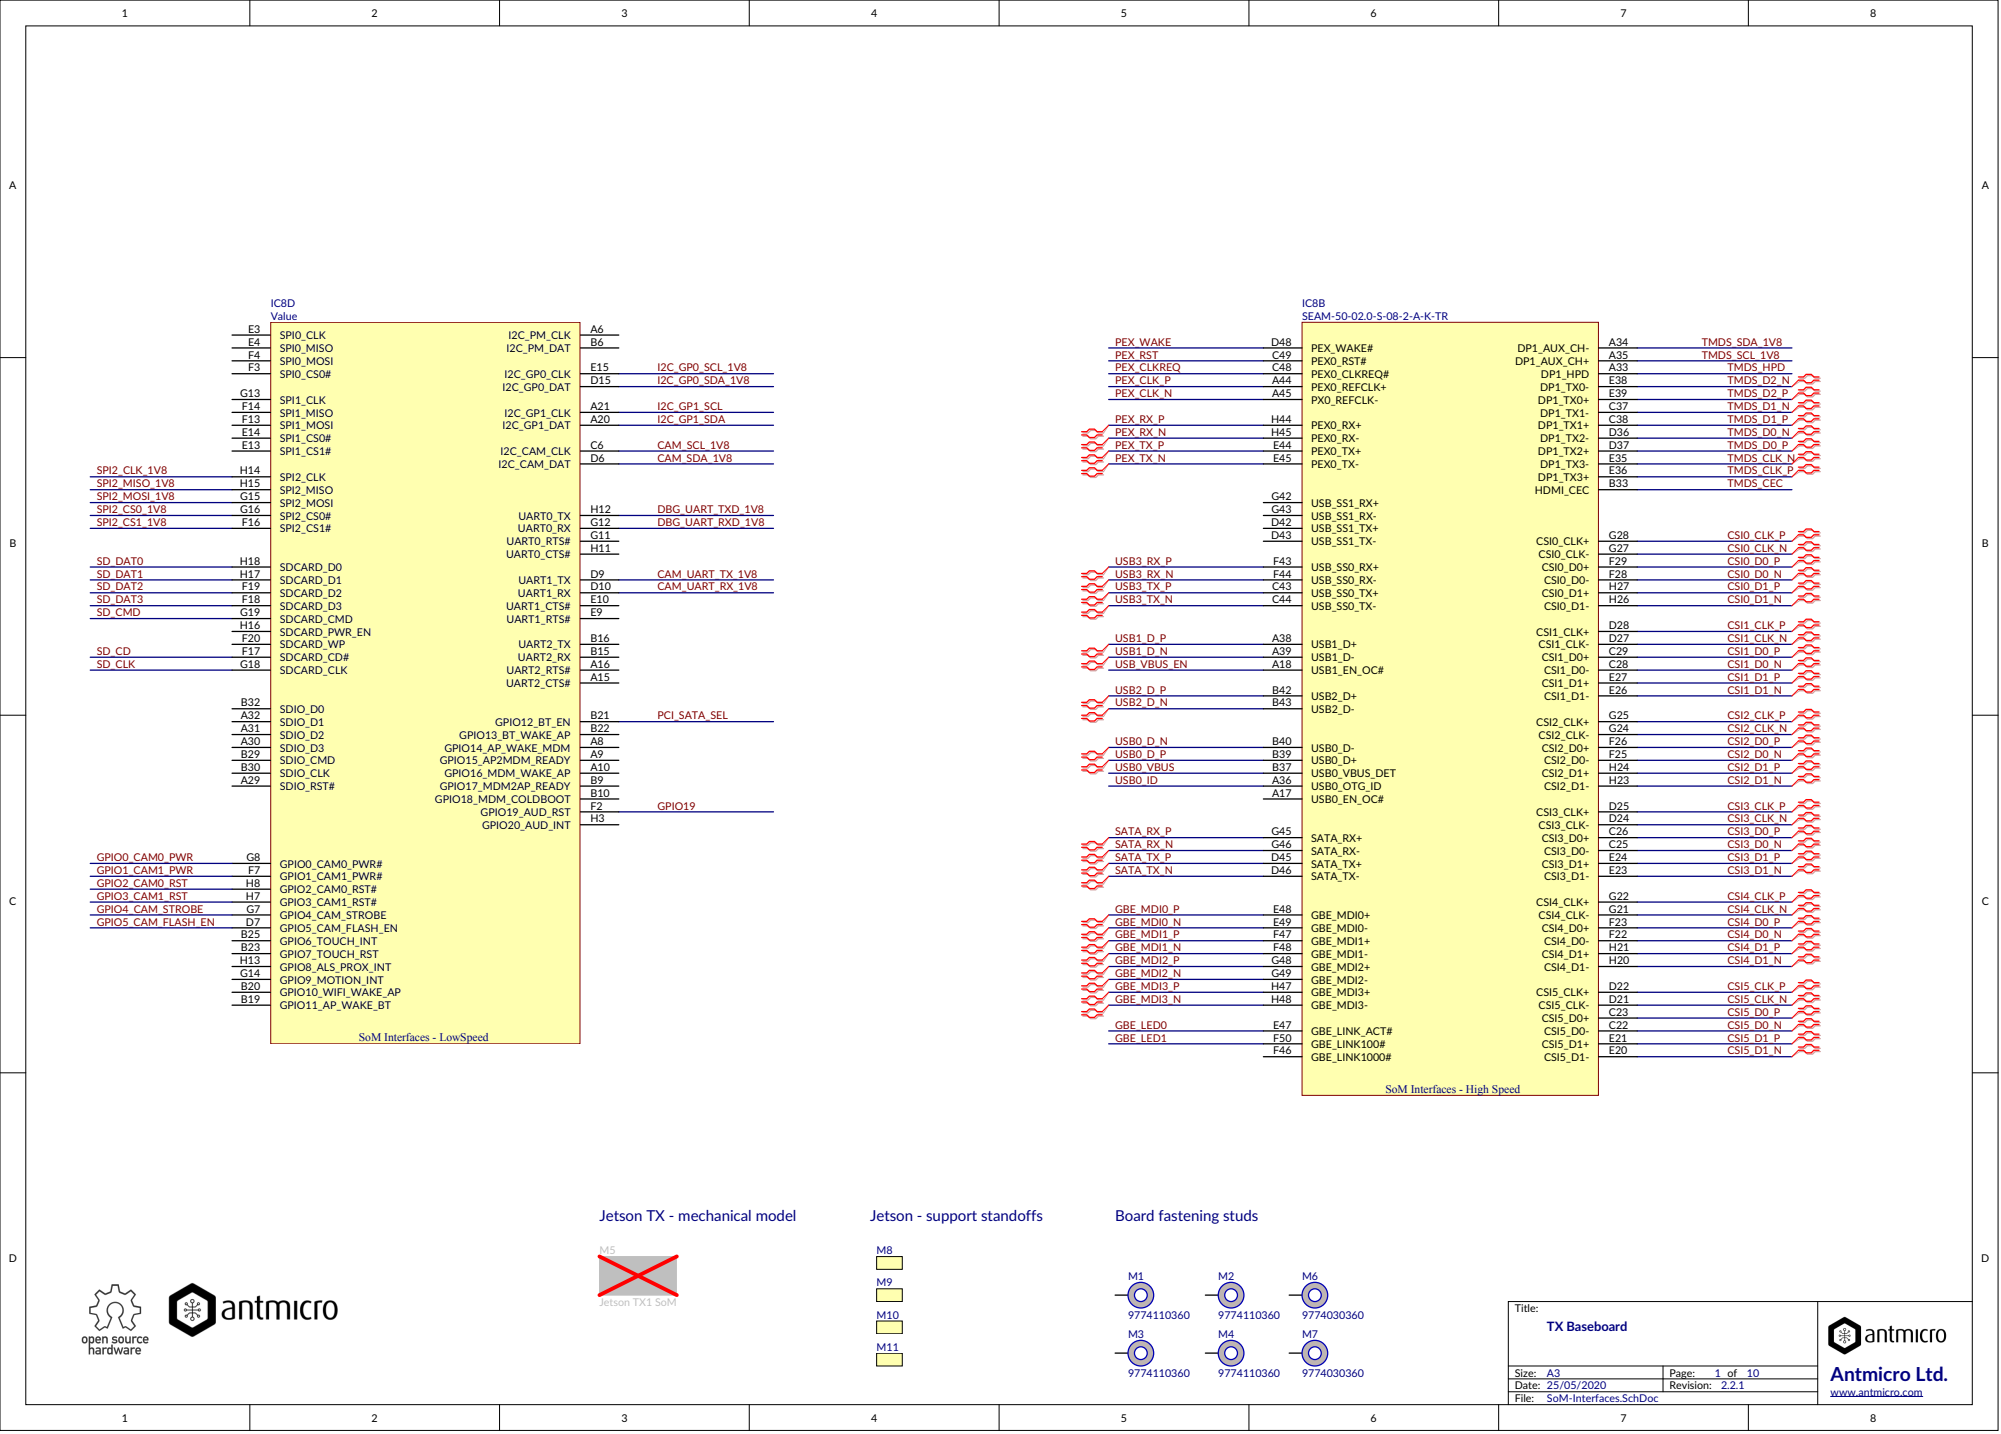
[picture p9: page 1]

SoM Interfaces - High Speed

Size: A3 | Page: | Antmicro Ltd. www.antmicro.com
Date: 25/05/2020 | Revision: 2.2.1

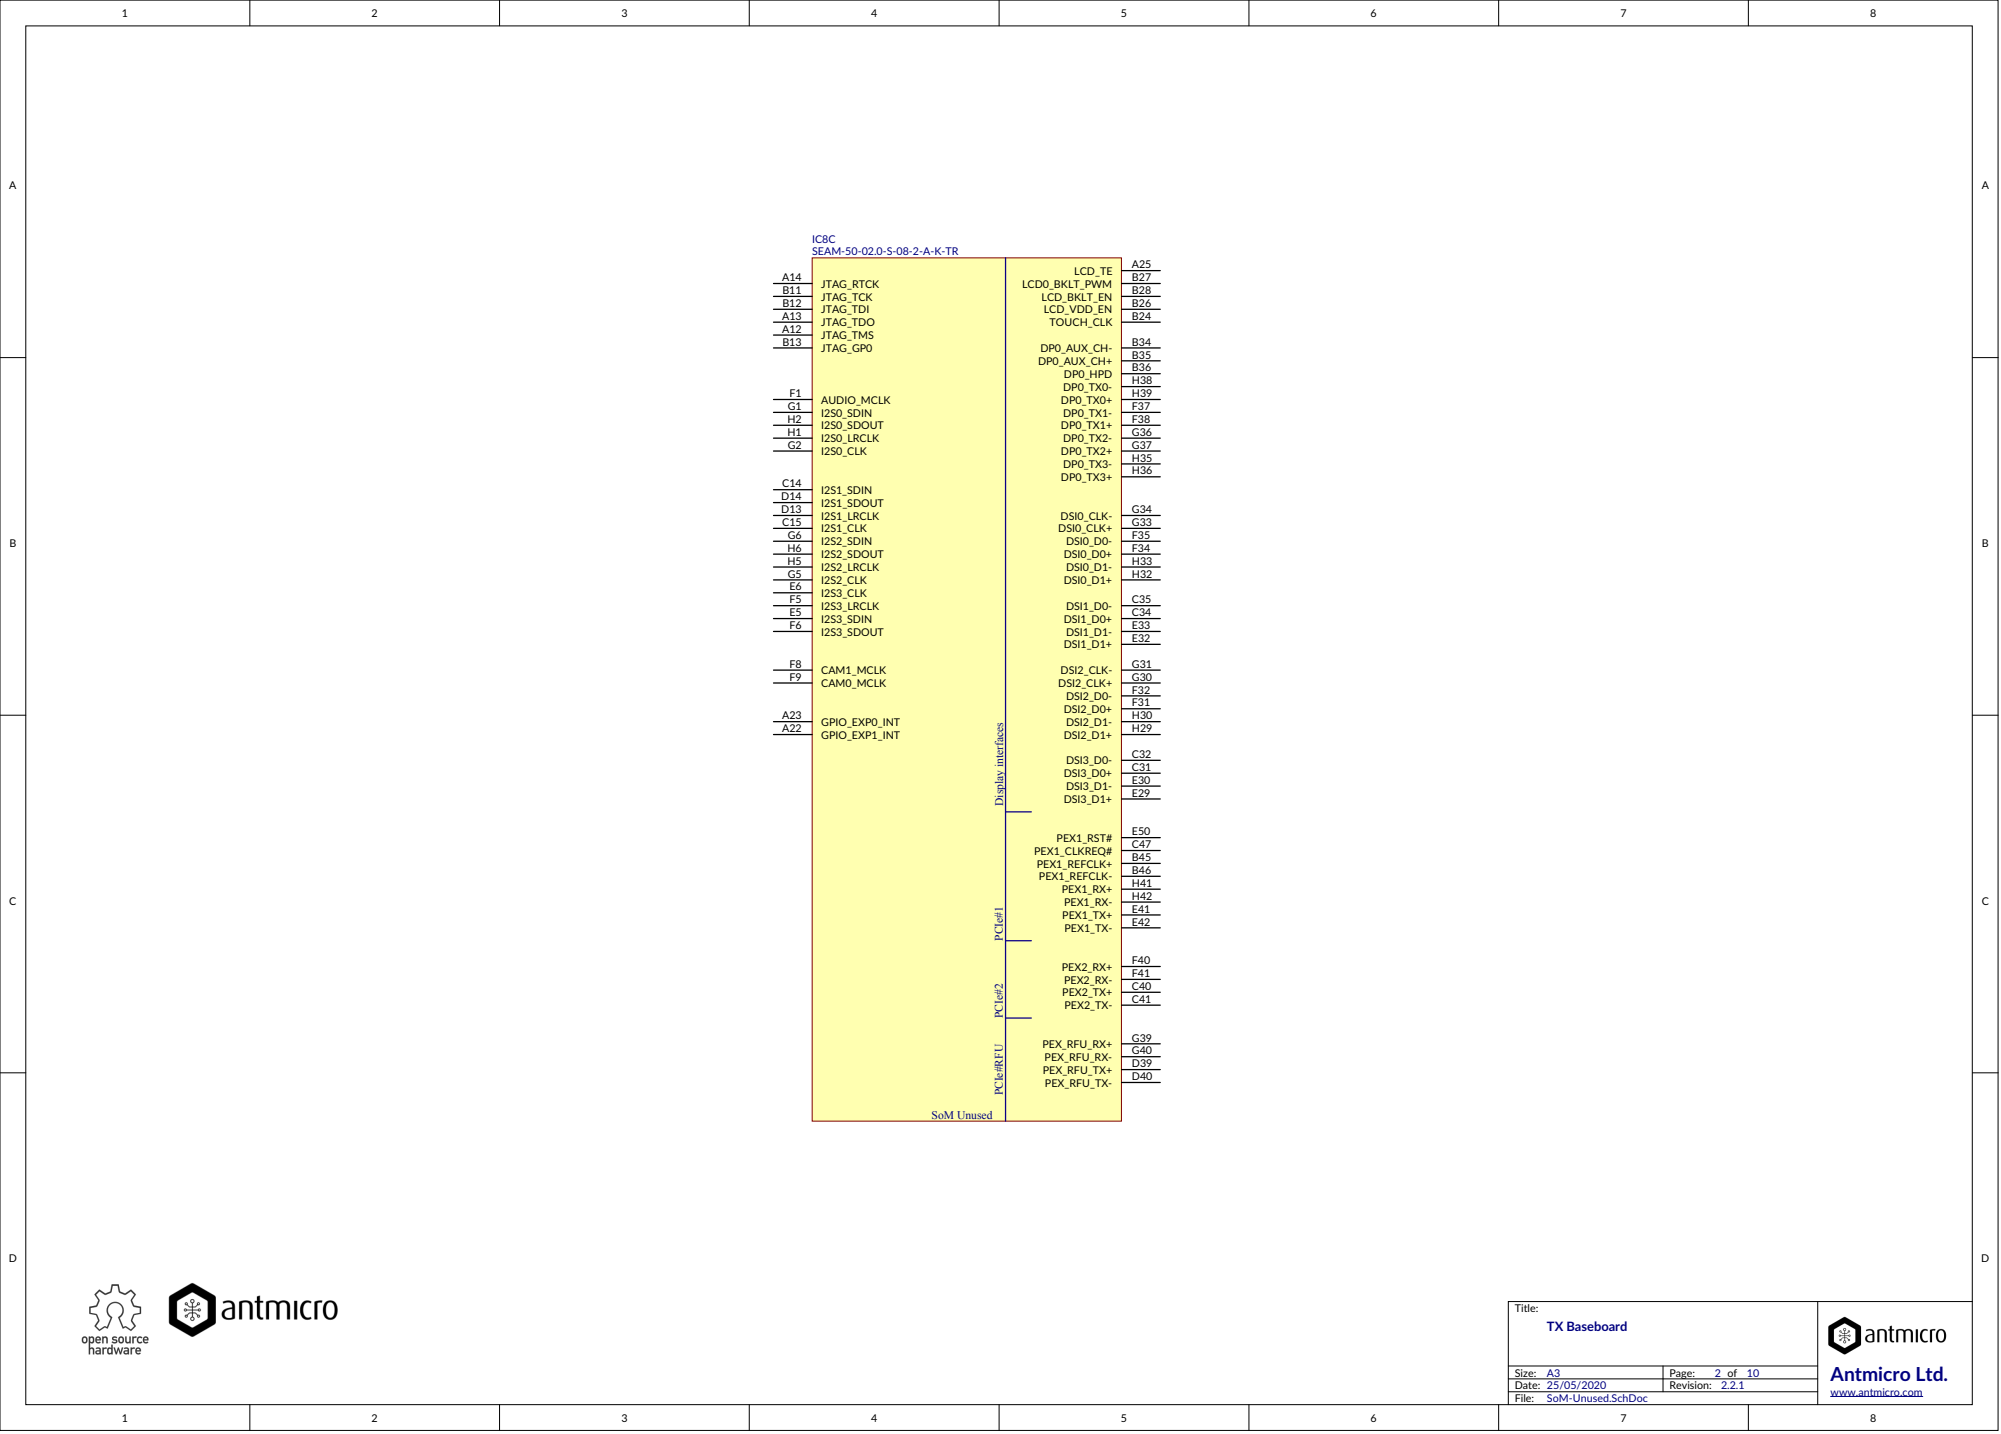
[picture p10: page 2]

Title:

A3 | Page:

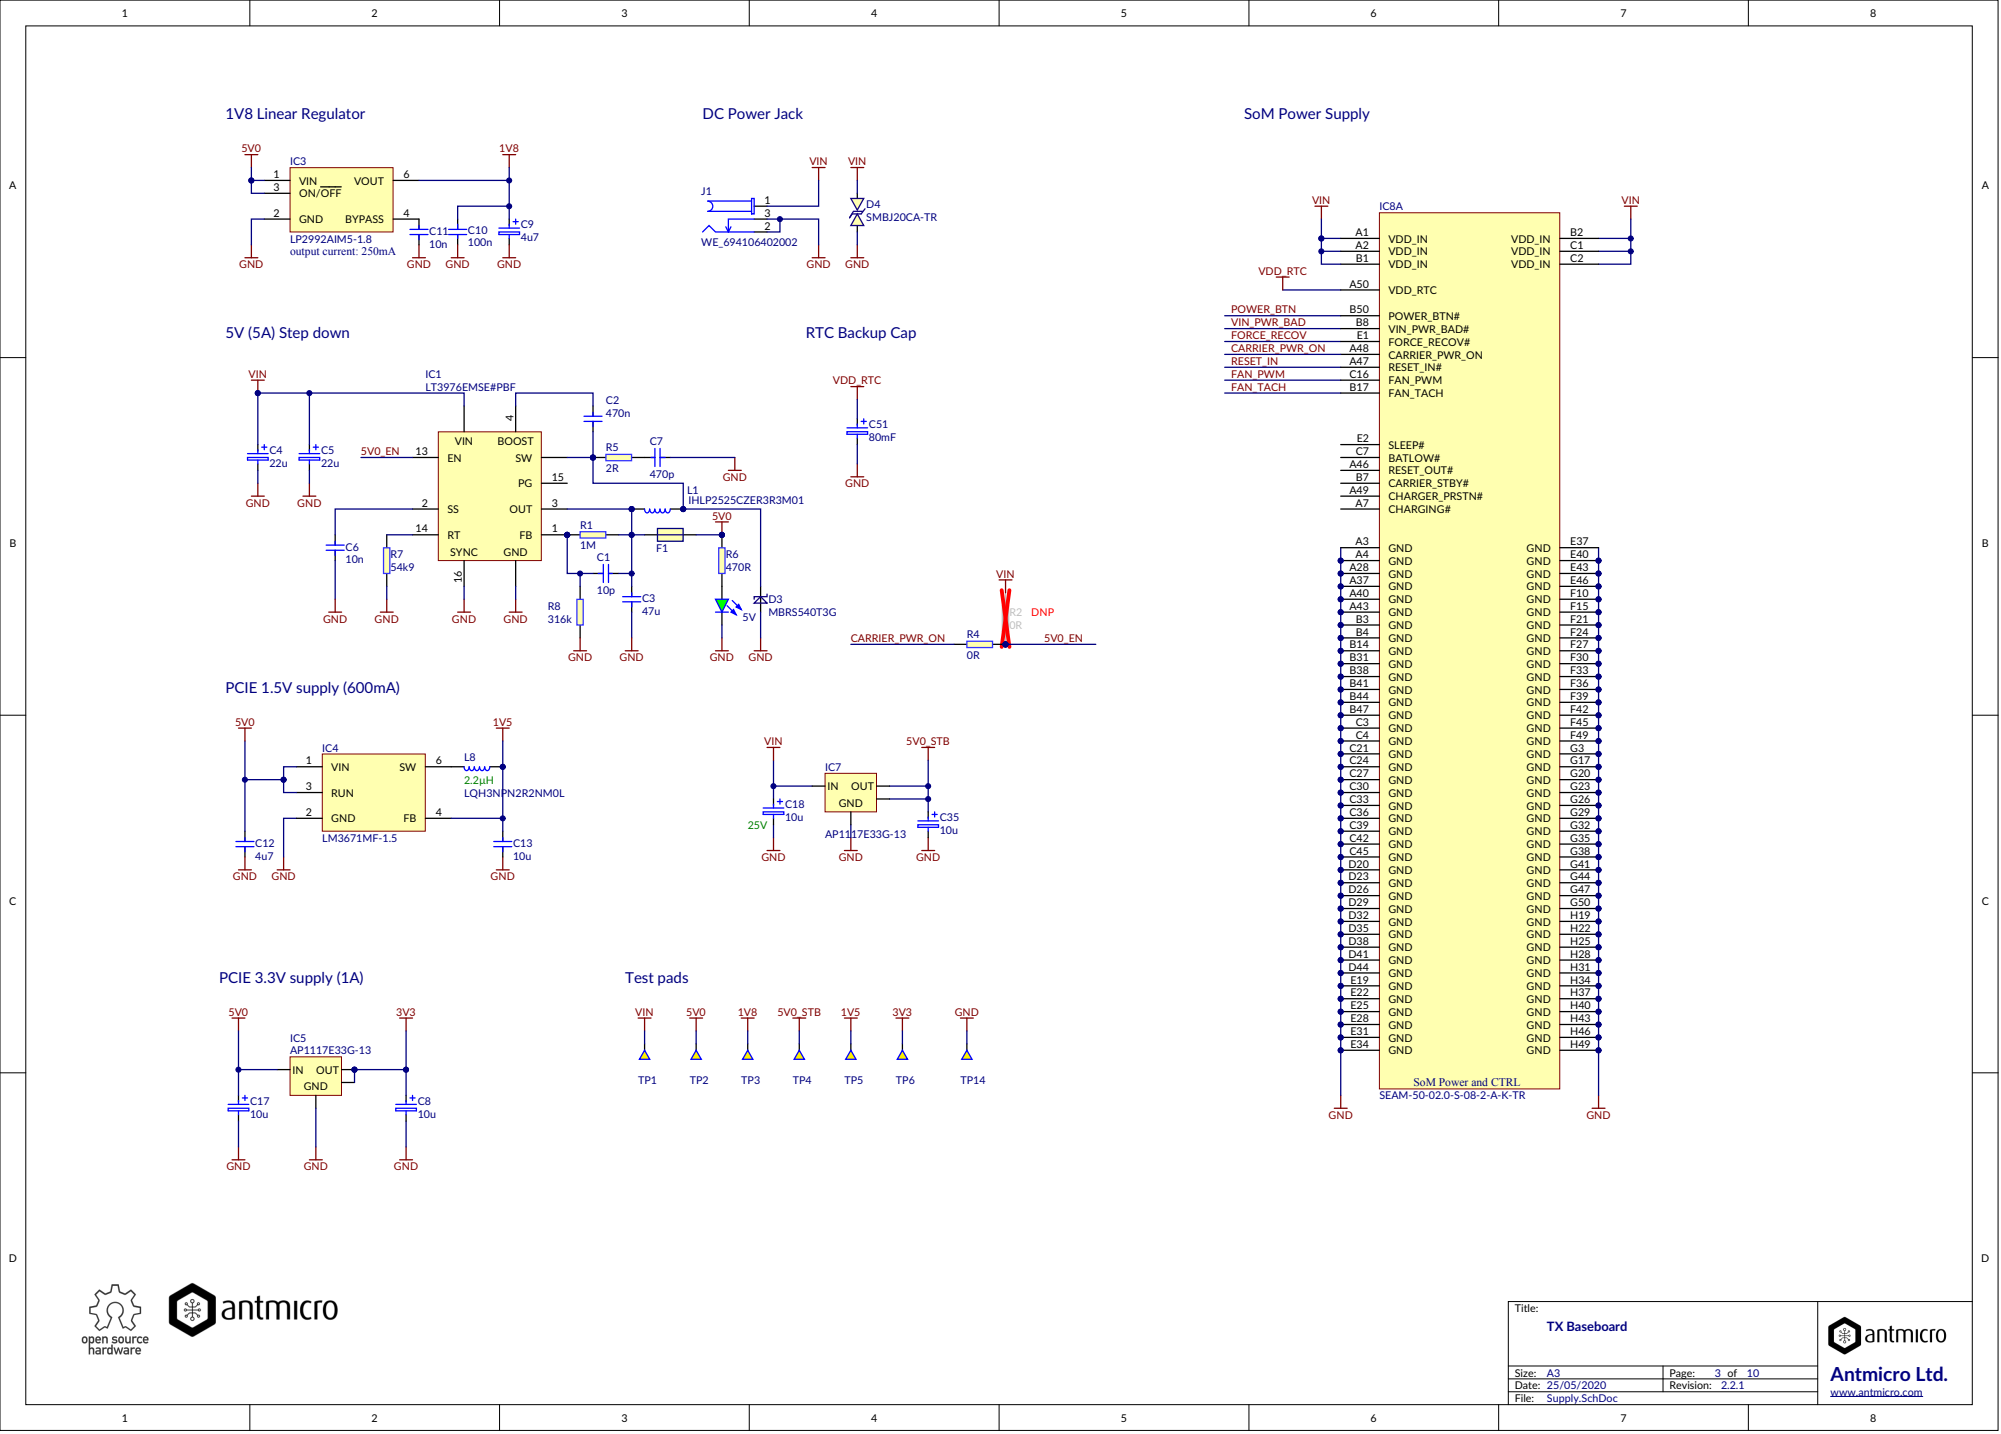
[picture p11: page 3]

VIN | SW GND

EN 13 SYNC

SoM Power and CTRL

Title:

A3 | Page: 3 of 10

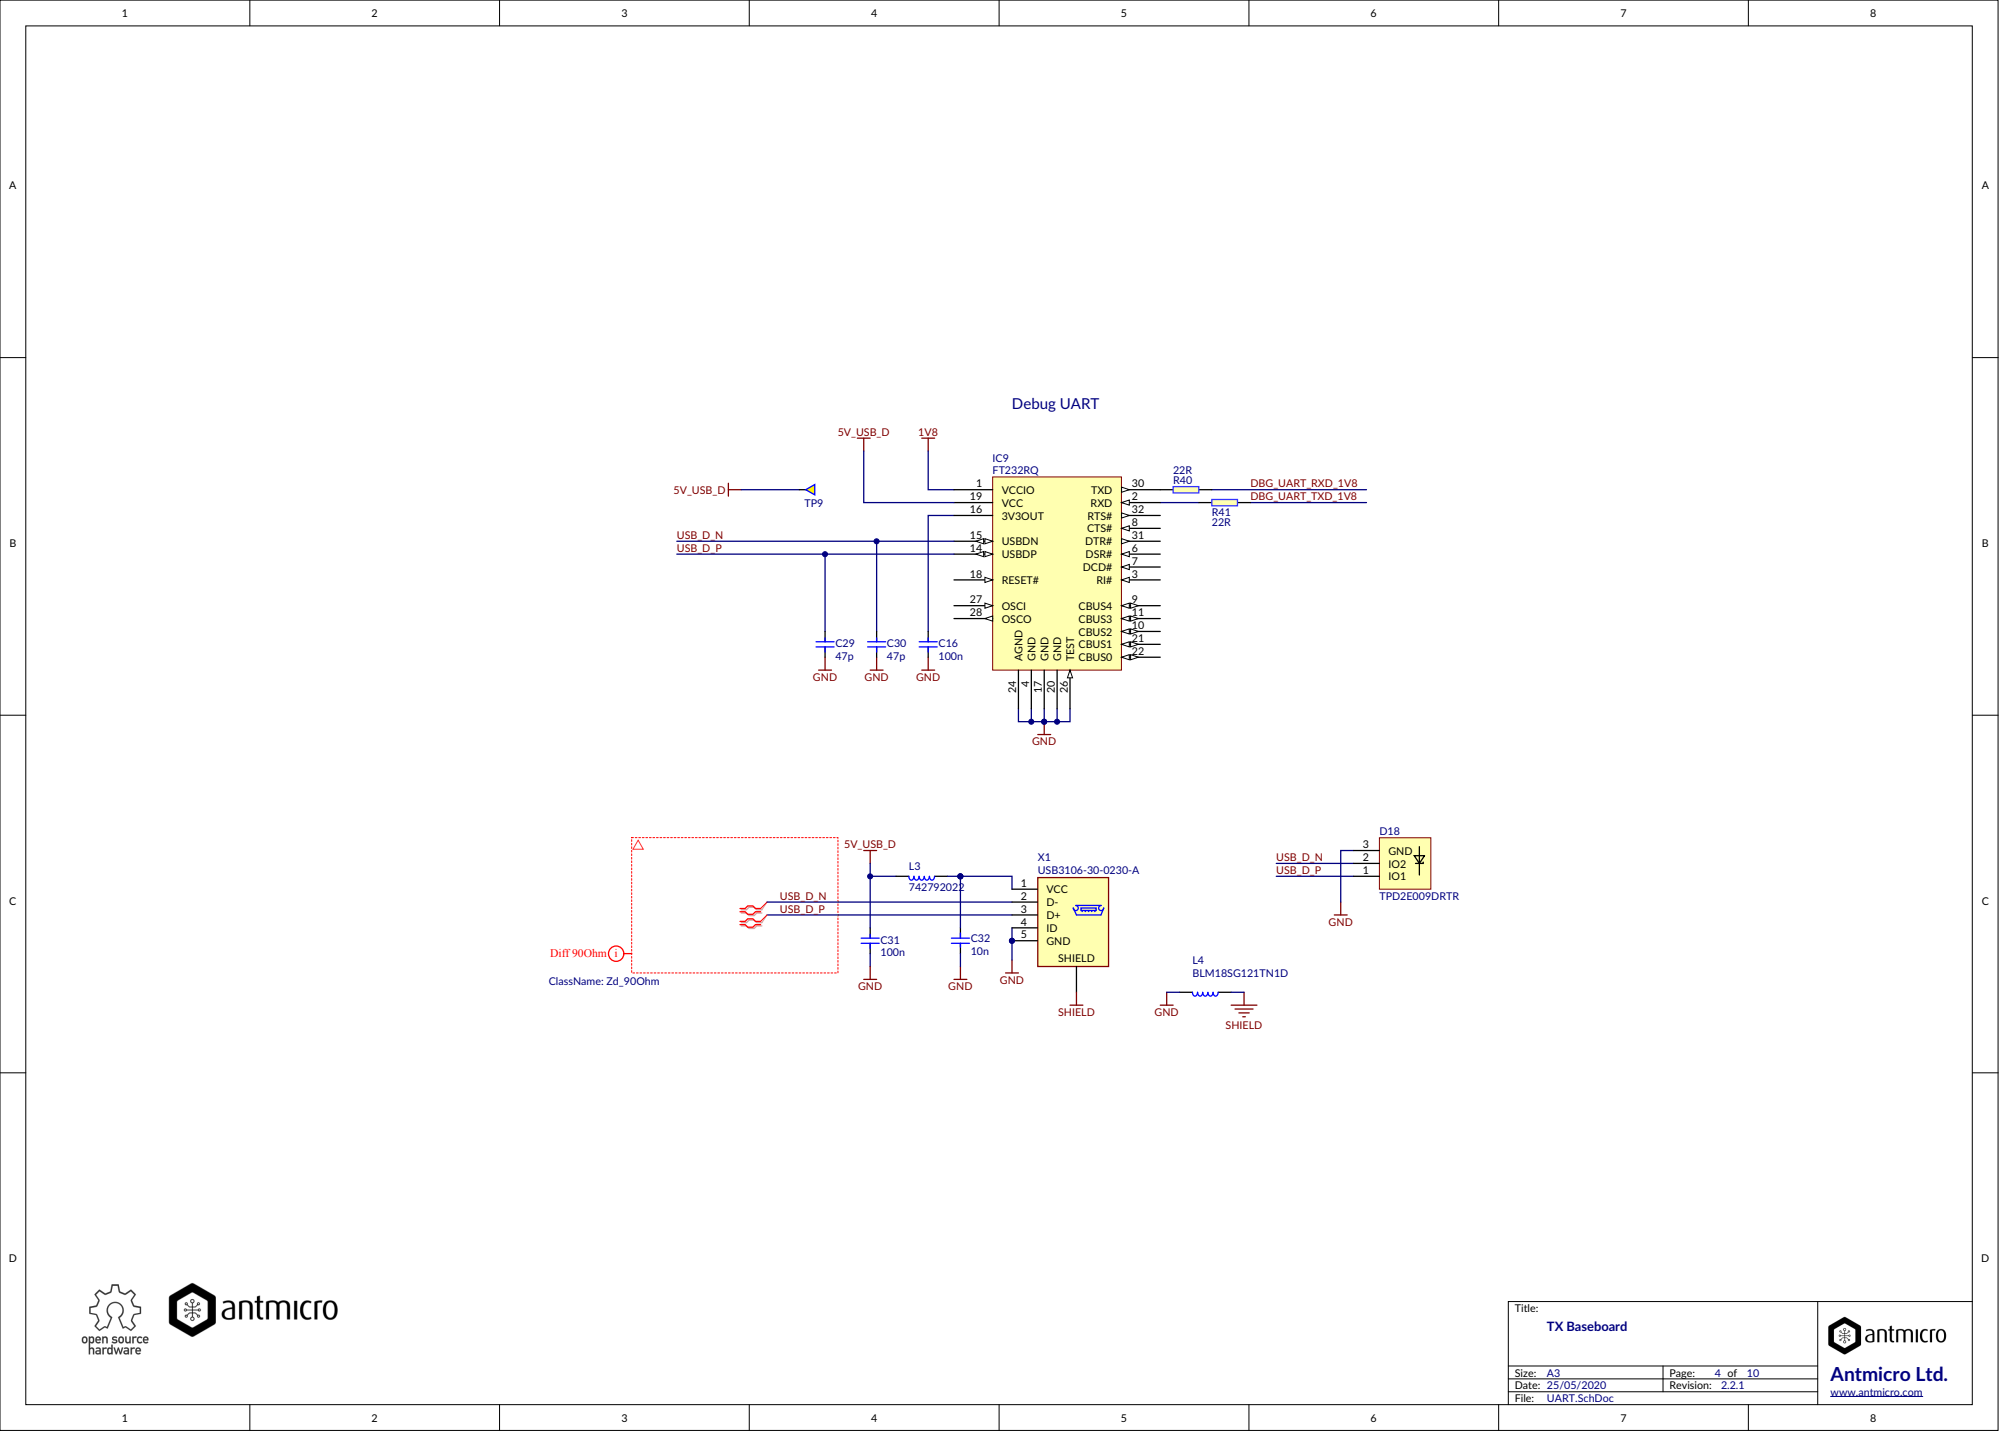
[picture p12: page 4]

3V3OUT 16

USBDP 14 USBDN 15 RESET# 18

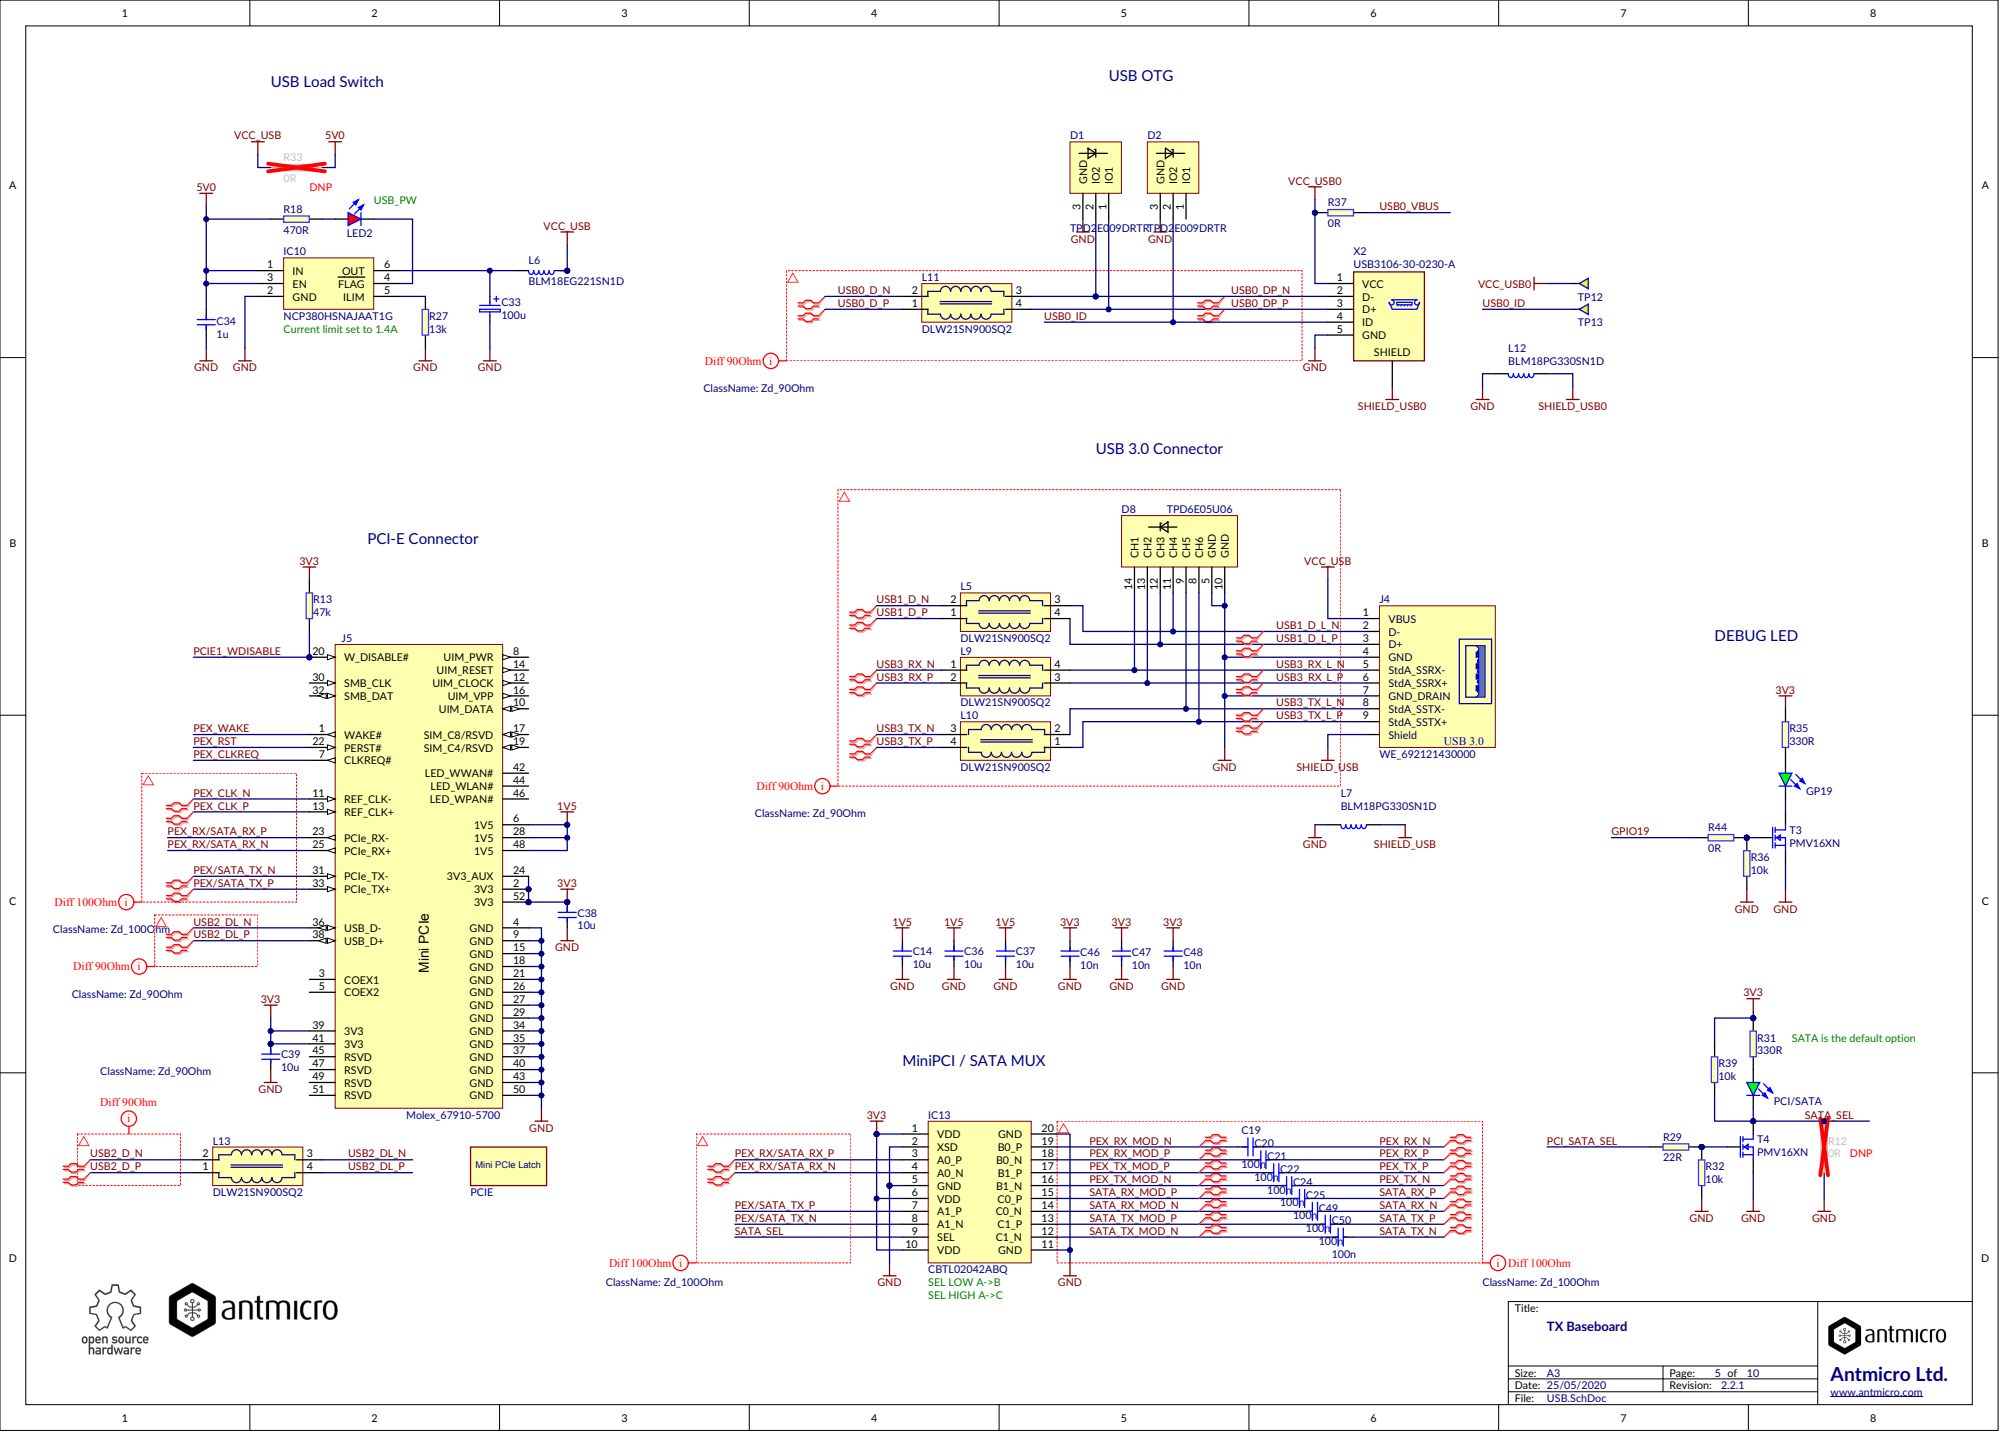
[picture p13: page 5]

4 | USB0_DP_P | | D+ 3
USB0_ID | | | ID 4

NCP380HSNAJAAT1G
Current limit set to 1.4A

GND 5

SATA is the default option

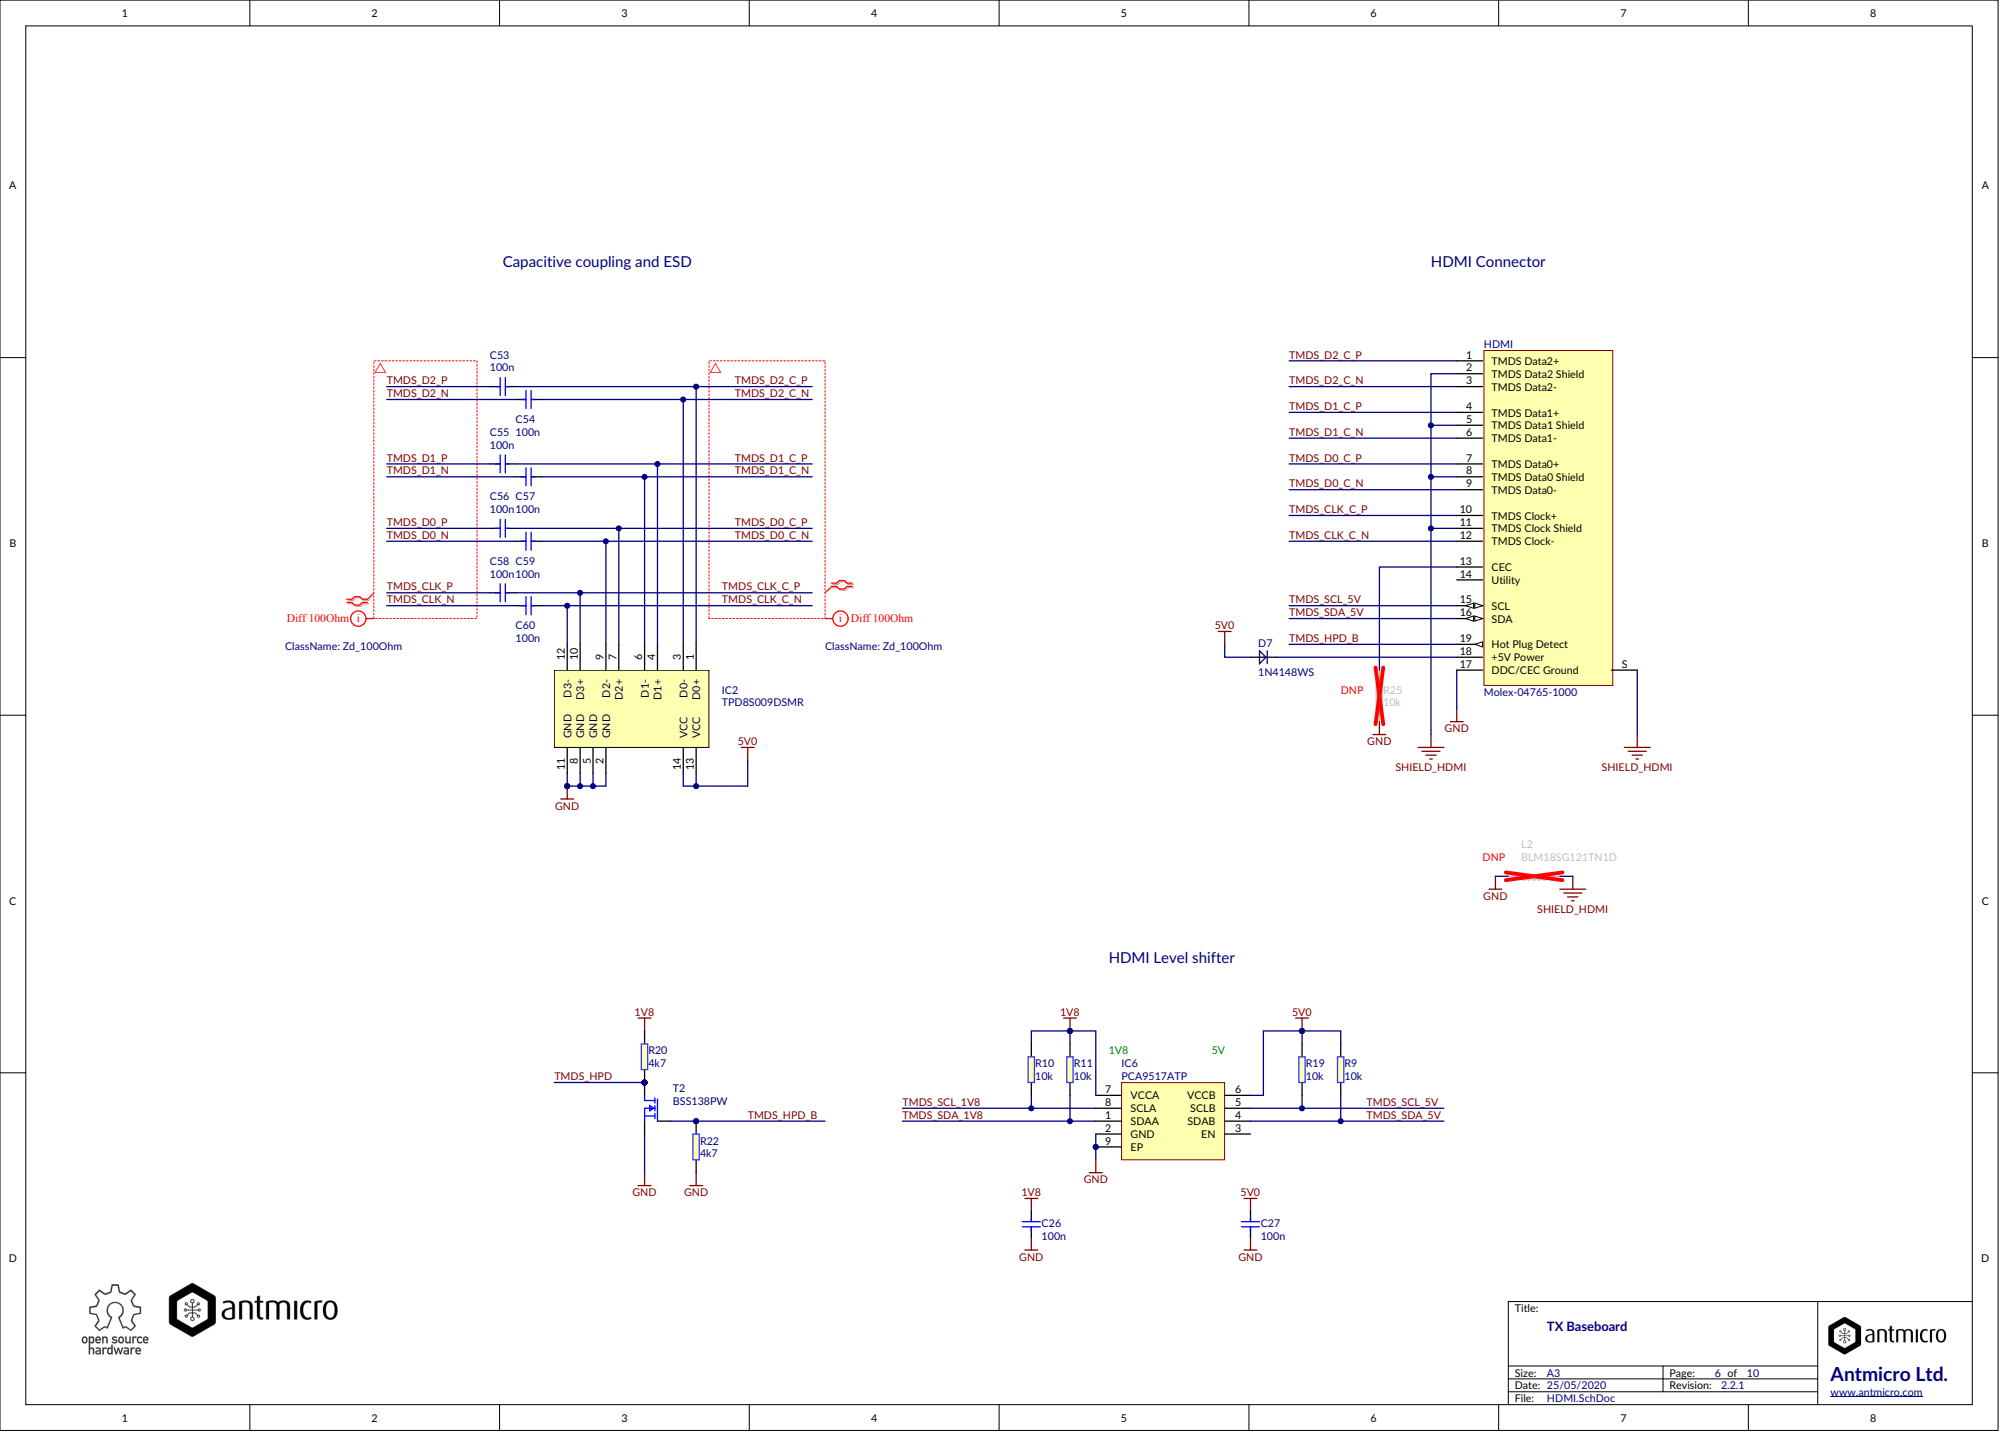
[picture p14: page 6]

Capacitive coupling and ESD

TMDS Data2- 3 TMDS Data1+ 4 TMDS Data1 Shield 5

TMDS Data1- 6 TMDS Data0+ 7 TMDS Data0 Shield 8

TMDS Data0- 9 TMDS Clock+ 10 TMDS Clock Shield 11

TMDS Clock- 12 CEC 13

Utility 14

DDC/CEC Ground 17

GND

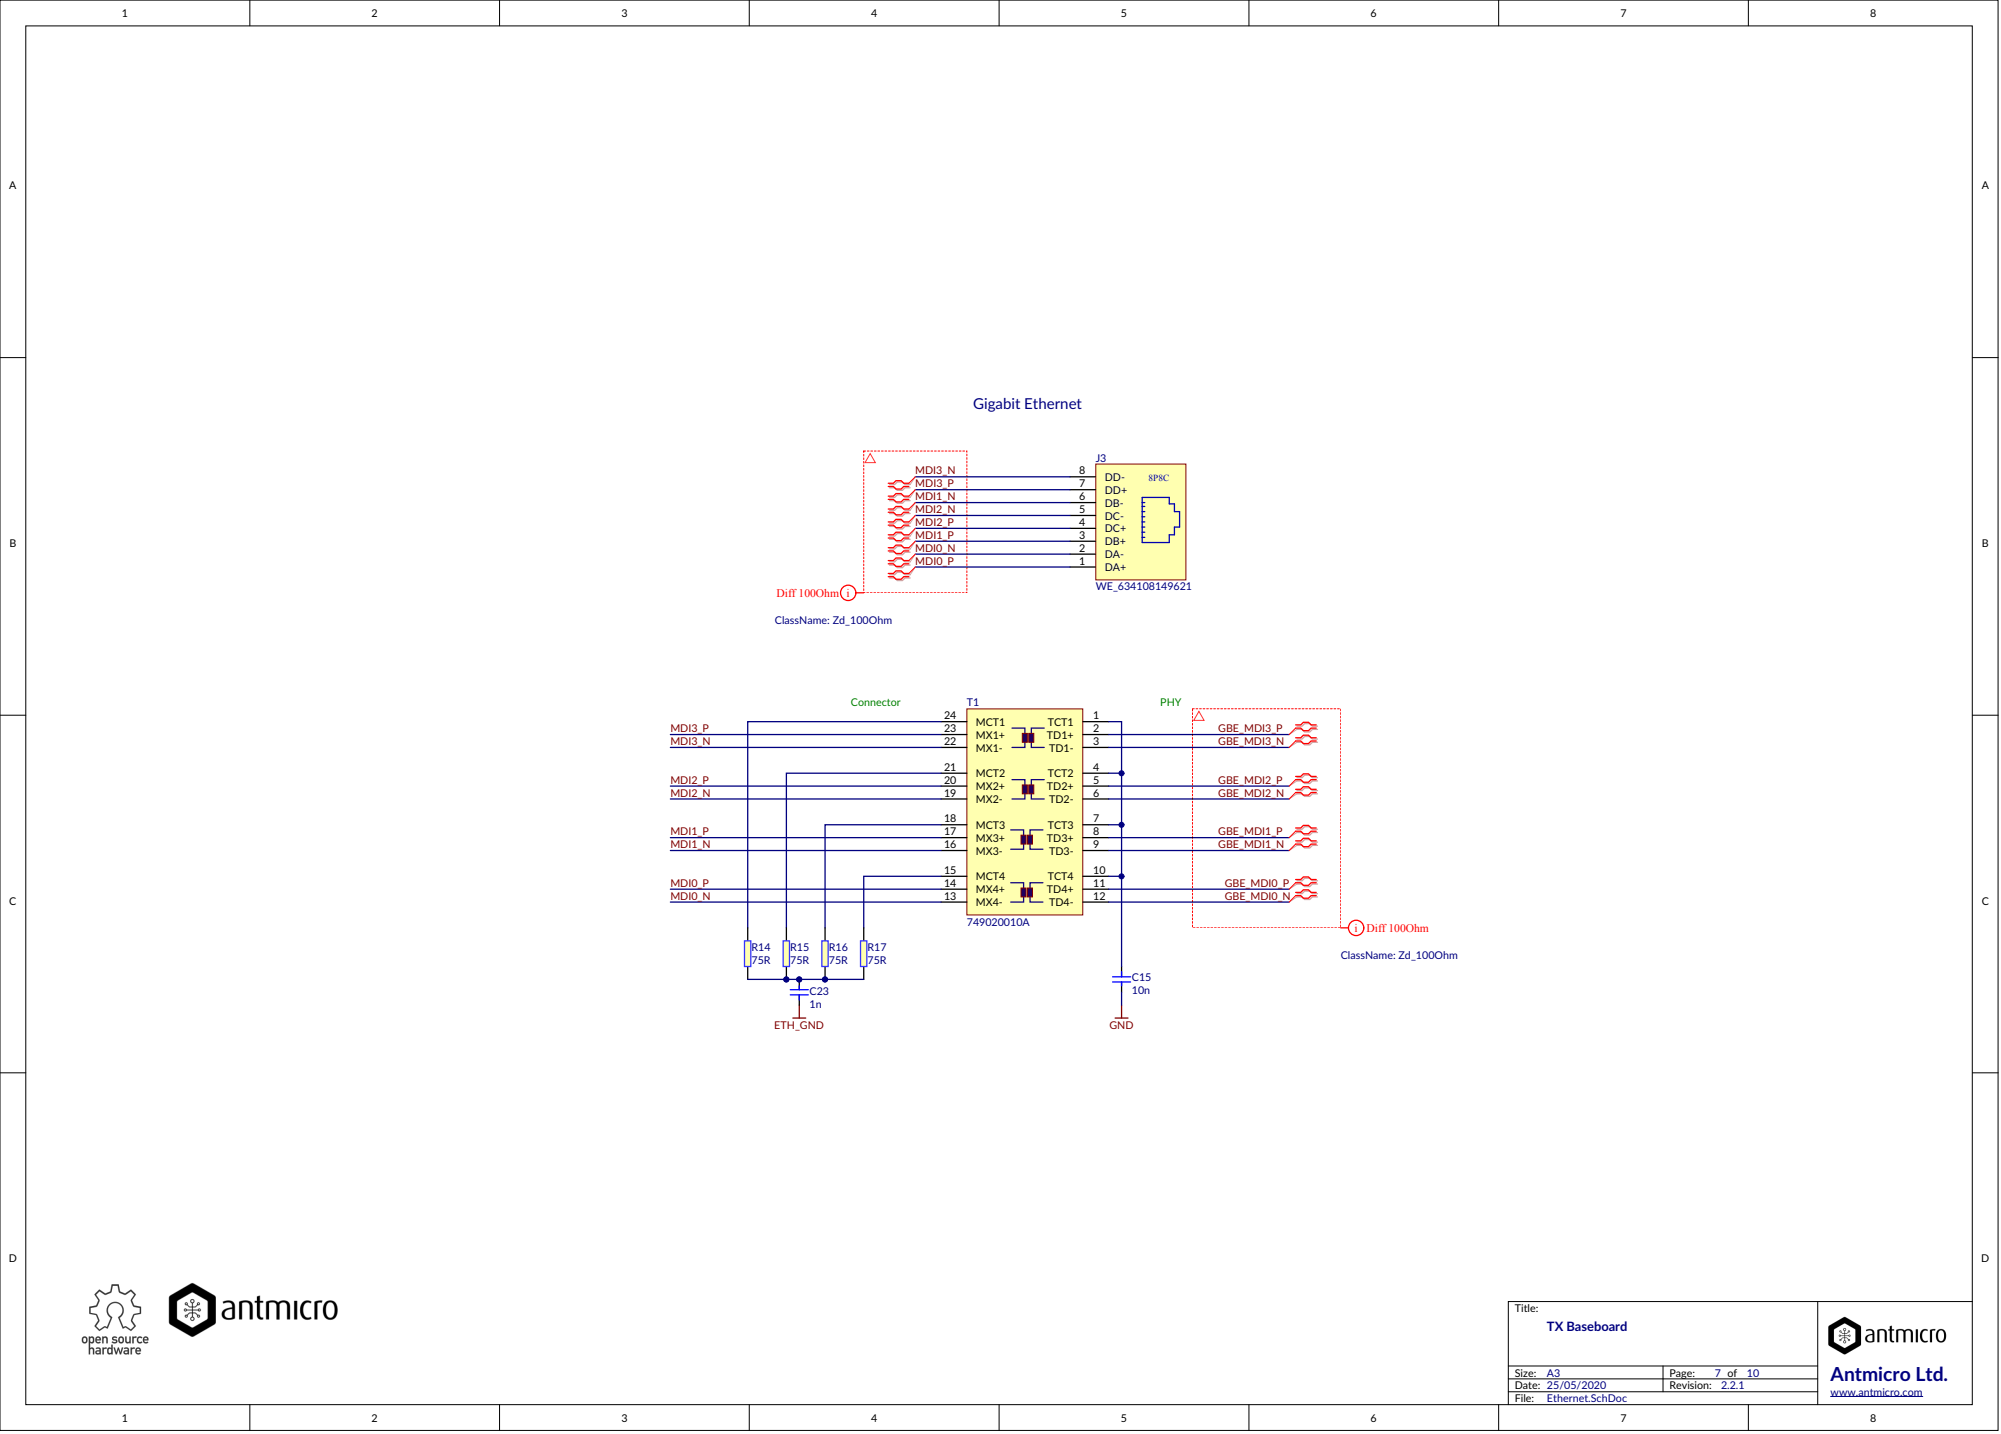
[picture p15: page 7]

MX3+ 17 MX3- 16 MCT4 15

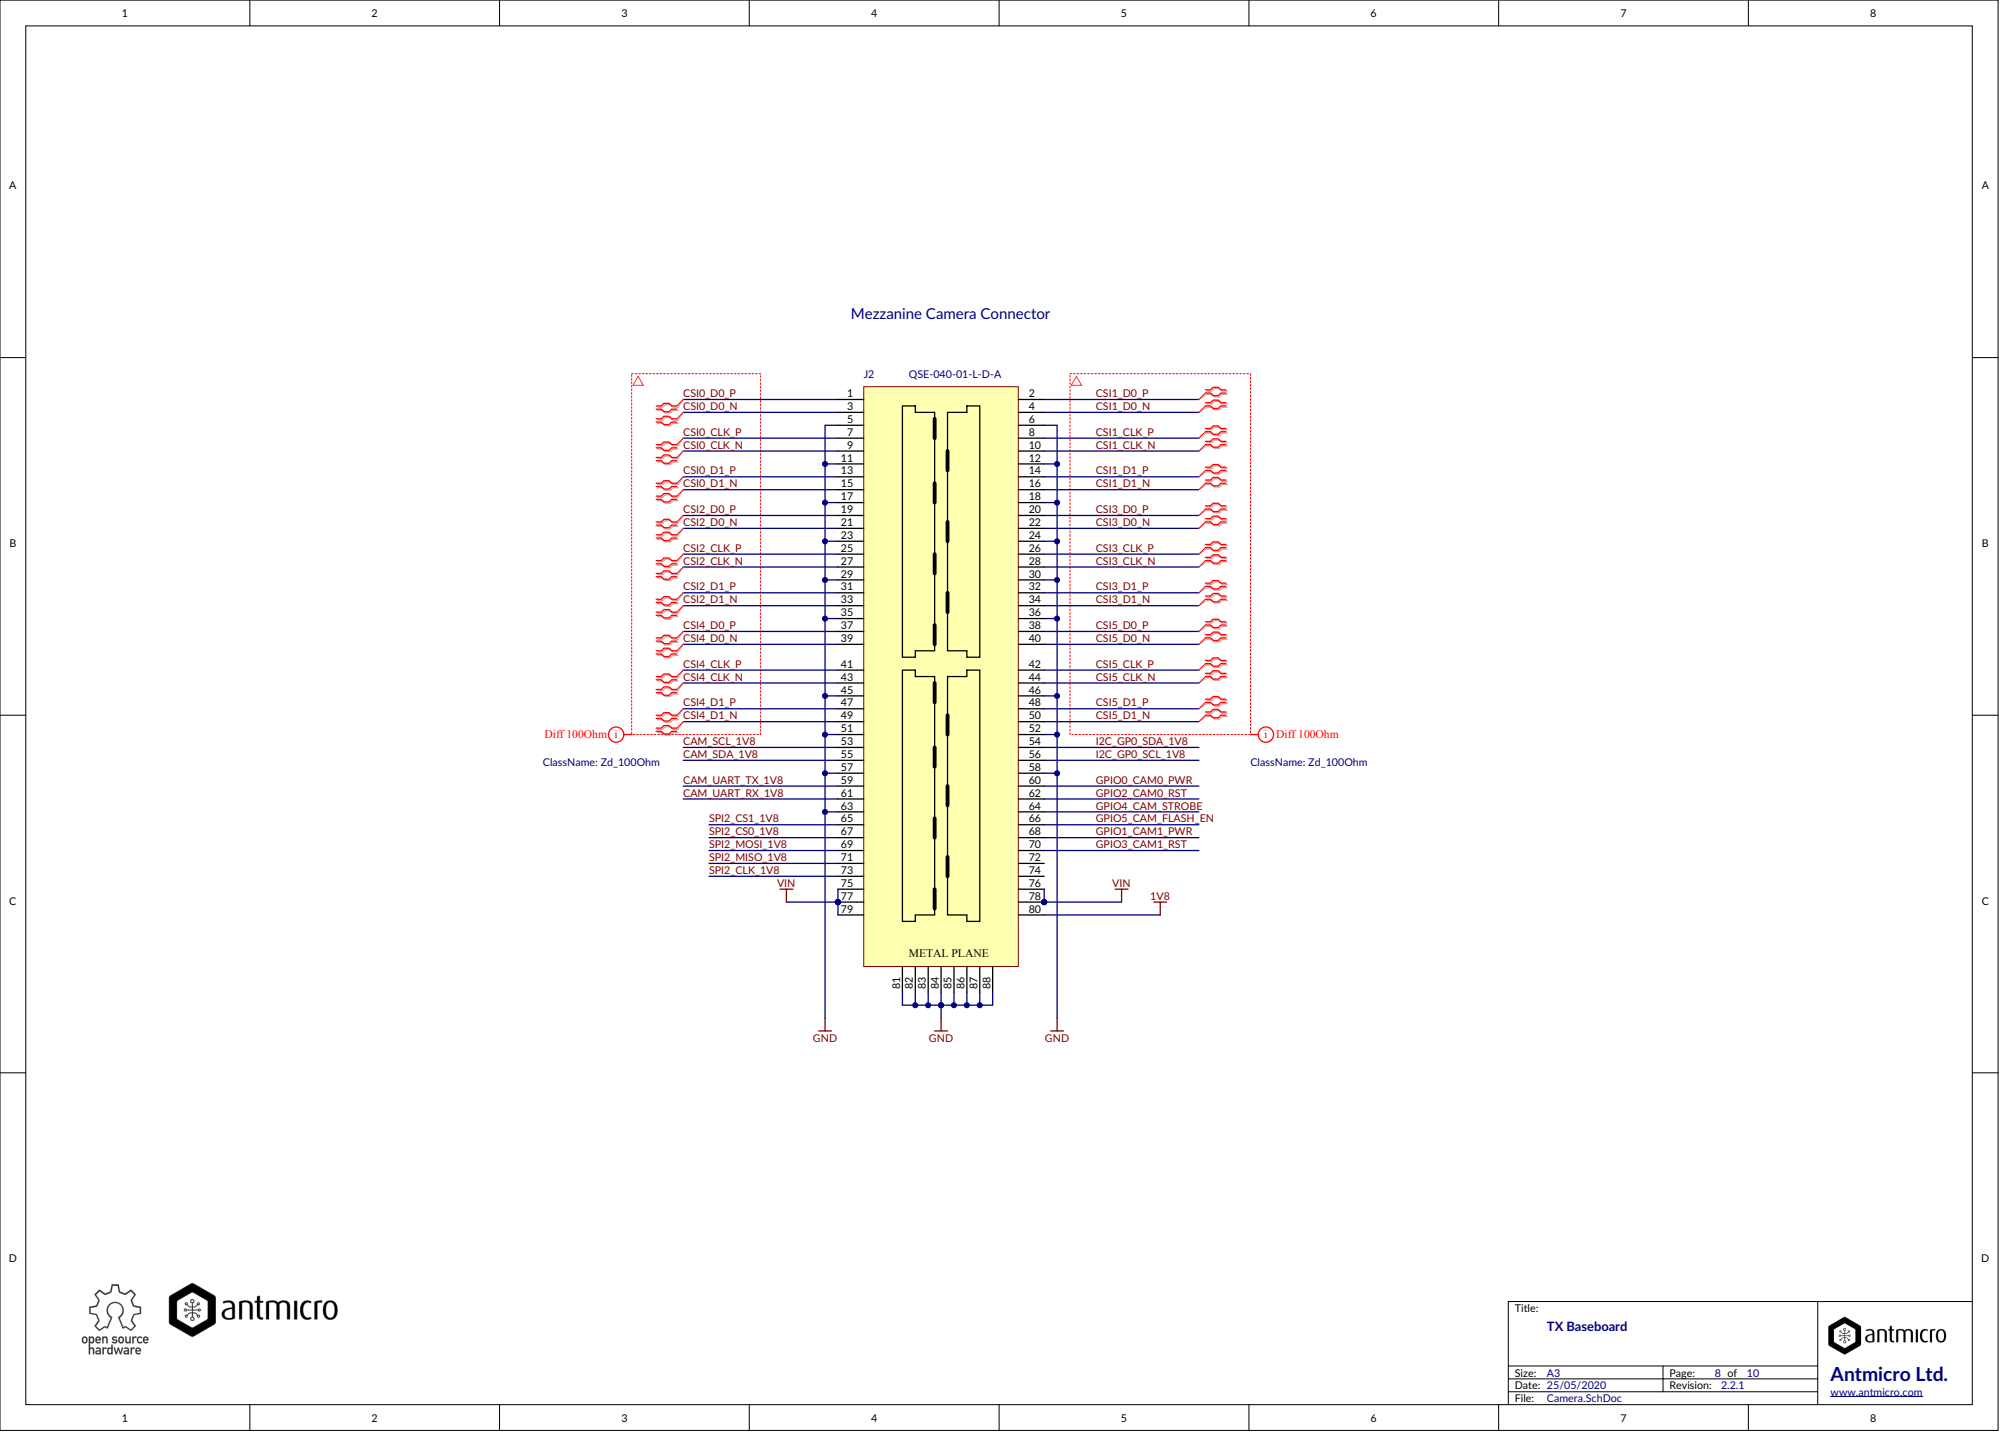
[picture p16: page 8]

Title:

A3 | Page:


NOTE: For TX2i applications R24 should be removed


Unique ID with OTP

Use BCD for writing hardware revision





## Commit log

2020-05-25 Add design files for release 2.2.1
    [Camera.SchDoc, Ethernet.SchDoc, HDMI.SchDoc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]
2020-06-02 Move the baseboard design into a separate folder
    [Camera.SchDoc, Ethernet.SchDoc, HDMI.SchDoc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]
2020-06-02 Add design files for camera adapter
    [CAN.SchDoc, Cameras.SchDoc, ID-Serial.SchDoc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]
